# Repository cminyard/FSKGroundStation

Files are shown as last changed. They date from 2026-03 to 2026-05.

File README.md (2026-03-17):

# FSKGroundStation

This is a hardware design for a low-cost PacSat satellite ground
station, but it is also general two-way FSK commmunication for the 2
meter and 70 centimeter bands.  It should be possible to build these
in the US $60 range in quantity.  It can do FSK variants ([G]MSK,
[G]FSK, OOK, ASK).  Notably, it cannot do AFSK, the normal 1200bps
communication used over FM radios.

Basically, this is two radios, one for around 136-175MHz, and one for
around 430-450MHz.  Each of these radios is a simplex two-way radio
using a basic ISM radio chip.  It then has an RF power amplifier (PA)
on the TX side to boost the power to the 4-5 watt range and an RF
switch after than to switch between transmit and receive.

The radios are TI CC1125 chips.  These are standard ISM radio chips.
However, those chips are not able to do HDLC or G3RUH 9600 as used in
standard amateur radio communication.  For that, the CC1125 can
send/receive raw FSK data out a GPIO port.  A Lattice ICE40LP1K FPGA
processes the FSK to be able to do HDLC and whitening per G3RUH.

These chips are controlled by a TI CC27x5 processor over SPI.  Also,
this is designed to have enough capability to run as a stand-alone
application, like for a balloon, fox, control device, or something of
that nature.

## Host Communication

Communication with the host is through a MSPM0G5187 processor that has
USB.  It has a SPI connection to the main processor.

There is also a 2.4GHz radio on the CC27x5 processor, so a bluetooth
connection could be done.

## RF Connections

RF input/output is through SMA connectors on the end of the board.
One connector is for 2 meters only, one is for 70cm only, and one has
a diplexer on it and can be used with a dual-band antenna.  You lose
about 1dB in the diplexer, so it's slightly better to have two
antennas.

There are two open-collector (open drain, really) outputs on a 3.5mm
audio-type jack that the CPU can drive for controlling external
amplifiers or for anything else, really.

Note that you really can't transmit on both bands at the same time.
Power draw would go somewhat above 4A and heat dissipation would be a
problem.  If you have a power source that can supply that it might be
ok, but it's pushing things on the heat side.

## Powering the Board

You can use either of the two USB connectors on the board to supply
power.  To use the host connector (J3), install the jumper on J8.  A
second USB connector J10 is a power-only USB connector that can be
used to power the board if the host connection cannot supply enough
current.  To use that install the J11 jumper.

There is also J25, a standard 6.0mm OD 2.5mm ID barrel connector on
the board, center pin is +5V and the outside is ground, as usual.  You
must remove the other power jumpers (J8 and J11) to use this.

All power connectors must supply at least 3A for transmit.

## Clocks

The MSPM0G5187 has a 32.768kHz clock with enough precision to handle
the USB connection.  In addition, it's internal oscillator has a high
precision resistor, so it should be good.

The 32.768kHz oscillator is output and send to the CC27x5 processor.
The CC27x5 processor has it's own 48MHz oscillator with 20ppm
precision.

The MSPM0G5187 also outputs a basic clock that is used to clock the
FPGA.

The CC1125 chips each have their own 40MHz 20ppm TXCO.

## Heat Dissipation and Measurement

The PAs produce a lot of heat.  At full power they will be dissipating
around 4 watts.  The heat mostly comes out through the bottom of the
board on a 2.5mm square copper pad under each PA.

There are a bunch of vias on the edge of the board and three
unobstructed ground planes between these vias and the PAs.  With edge
plating, this should be able to move heat from the ground planes into
the chassis from the edge.  This is experimental.

In case the edge vias and plating don't work, the 2.5mm square copper
pad under the PAs is left bare.  That way a thermally conductive pad
or a heat sink can be put on that to move heat away.

There are two thermsistors on the board, one mounted by each PA, for
measuring temperature.

## Design Variants

Lots of things can be removed if not required, which will decrease the
price and allow slight performance improvements in some cases:

* The 3.5mm external PA control jack and associated circuits can be
  removed if not necessary.

* PacSat satellites transmit on 70cm and receive on 2m, so the ground
  station for that really only has to transmit on 2m and receive on
  70cm.  The 70cm transmit circuits could be removed and the 2m
  receive circuits could be removed.  That means you can remove the RF
  switches on the, gaining about 1dB.  That, of course, makes the
  board less flexible for other purposes.
  
* The diplexer and connector can be removed if not needed.

* If only the diplexer is used, the TX and RX connectors can be removed.

* The radios can be modified to different bands up to the capabilities
  of the various parts.  The limiting factor is the bands supported by
  the radios (TI CC1312R and CC1125 chips) and the capabilities of the
  PA (Guerrilla RF GRF5604, 100-600MHz).

* The power connectors that aren't used can be removed.

## A Box

This was designed to go into a 100mm x 88mm box like:

    JIUWU Surface Drawing Split Aluminum Enclosure Project Box
	Electronic Enclosure Case for PCB Board DIY, 88x38x100mm (WHL),
	Black

on Amazon.  The actual board dimensions are 83mm x 100mm, it should
slide into the slots in the chassis, which is supposed to be 84mm
wide.

## TODO list

* Figure out how to handle heat from the PAs.

  * Screw mount on the bottom.  This would probably require putting
    the external connectors on the bottom of the board to give space
    in a box.  It would also require ventilation of some type and
    maybe a fan.
	
  * Connect a heat transfer device to the box surface.  This would
    require mounting in a box.  If you use the box referenced above,
    there is a 5.2mm gap between the bottom of the circuit board and the
    inside of the box.  I'm not sure how to conduct the head, though.

  * Wurth has some "Graphite Foam Gaskets" that have high thermal
    conductivity and are not electrically conductive, from what I can
    tell (1KV/mm dialectric strength), and not too expensive.  Laird
    has "Thermal Transfer Gaskets," which look similar.  Also
    Bergquist thermally conductive gap pads.  You could put that
    between the PA pad and the chassis.  I can't find one that's the
    right height, though, it needs to be 5.2mm.  Maybe it can be cut?
    The custom make them, but that would be expensive.

  * It would be possible to use 2oz copper on the inner and/or outer
    layers.  This will conduct a lot more heat, but limits the board
    stacks that can be used and requires some impedance adjustments.

  * The edges of the board could be plated, allowing heat transfer out
    of the edges of the board into the chassis.

* The 2m connection to the CC1312R is actually for 169MHz.  A proper
  design for 145MHz needs to be found, or it will need to be tweaked.

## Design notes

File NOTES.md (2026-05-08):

Notes on the FSK Ground Station
===============================

This keeps track of history, general information, things that need to
be done, and things that have been done.

The general information will probably make it into another document at
some point.

# TODO

I discovered that the CC1125 lets you have direct control over the TX
output and direct read access to the RX frequency offset.  See "5.2.4
Custom Frequency Modulation(CFM)/Analog FM" in the manual.  It appears
you can set up the chip to continuously read/write these values
through the SPI interface.  With this, we have the possibility of
directly modulating and just using the CC1125 as an RF front-end.  You
could probably do AFSK with this.  You could get certainty information
on bits for doing soft decoding of FEC.  This will require some
redesign.  To use this requires a dedicated SPI interface for each
radio.  This would require a new CPU or using the FPGA to do the SPI
interfaces to the radios.  It would also require doing signal
processing somewhere for AFSK.

When a smaller version of the MSPM0G5187 comes out, switch to it.  The
64-pin LQFP takes up a lot of space and has tons more pins than this
needs.

It is unfortunate that two CPU chips are required for this.  But the
existing USB chips have proprietary elements and very poor
documentation if you are doing anything but a serial port.  Plus they
are more expensive than the MSPM0G5187.  But I couldn't find a chip
that had enough FLASH and RAM, bluetooth, and USB.

# Done

Possibly replace the USB chip with a MSPM0G5187.  It's a
microprocessor with a USB interface, and it's actually cheaper than
the CY7C65215-32LTXI and it frees us from using lousy libraries from
the vendor and proprietary programming tools.

# Not going to do

# Chip Selection and Possibilities

PA final: PD55015 15W 15dB gain, 12.5V, could be pushed a bit

PA stage 1: GRF5030, GRF5040, GRF5112, GRF5115, etc.  Some Qorvo chips
would work.

GRF5604 is capable of 6 watts (38dBm, 37dB gain) and it is a two-stage
design, so only one chip is needed to get to 6 watts.  This was chosen
for now.

For the radios, a large number of ISM chips are available, but few
will do 144-149 MHz.  The TI CC1312R and C1352R are Cortex M4F CPUs
with an attached radio.  They cannot do HDLC, though.

The TI CC12xx series of radios are similar to the CC1312R but stand
alone radios.  They will not directly do HDLC or the G3RUH whitening,
but they have something called "Synchronous serial mode" that appears
to put/get the FSK directly on GPIO pins, so you could do HDLC on an
external chip.  It also has something called "Transparent mode" that
appears to give direct access to ADC info and the TX synthesizer.

The Silicon Labs 446x series of radio chips is very similar to the TI
CC12xx series.  It has "direct mode" which inputs/outputs FSK and "raw
data mode" which is the ADC and TX synthesizer access.

For bit handling (HDLC and whitening), the Lattice iCE40 LP/HX series
of FPGAs looks good.  Probably the LP640 or the LP1K.

For a USB interface, FTDI has a bunch of chips that look workable.
They are on the expensive side, though.

Infineon has some chips, too, and CY7C65215-32LTXI looks good.  It has
a dual interface that can do UART, SPI, and I2C.  The plan is to do
UART and SPI for the host interface.  One problem is that the various
chips (from FTDI, Microchip, Infineon) have very poor documentation on
how to program them; they expect you to use their libraries

TI and some others make a chip with USB that could be used, too.  It's
cheaper, and it doesn't tie us to proprietary tools.

If we use the CC1352R, it can also do Bluetooth, which might be nice
for a host interface.  It doesn't cost a lot more than the CC1312R.

If we have two independent radio chips, then other non-radio
processors can be used.  The Cortex-M0+ processors could be used,
though they are limited in RAM, but they cost less than $1.
Cortex-M4F processors would be better.  It turns out it's cheaper to
buy the CC1312R or CC1352R than just a plain Cortex-M4 from TI.
And the radio chips have more flash and RAM.

But even better, the TI CC2755 chips are cheaper and have even more
FLASH and RAM.  And they can do bluetooth.

# History

## 2026-03-06

Initial basic design was done a few days ago.  Original design was a
CC1312R processor+radio for 144MHz and a CC1125 radio for 440MHz, and
two GRF5604 PAs.  The host interfaced is a CY7C65215-32LTXI.

However, I have discovered that the ISM chips that are cheap and easy
to use will not do HDLC or the G3RUH whitening.  I've also learned
some information about G3RUH:

I had always been a little confused about g3ruh modulation based on my
understanding of how modulation works and what g3ruh does.  I had
heard that g3ruh was GMSK.  That's not true, it's GFSK.  I had
wondered how it knew where the zero crossings were.  There's actually
a note in the PacSat software saying that GMSK didn't work on receive
and they had to use GFSK to receive.  And now I know why.  You can
transmit GMSK and a GFSK receiver will receive it, but you cannot
transmit GFSK and have a GMSK receiver receive it.  Unfortunately,
there's no really good explanation about g3ruh, I had to reverse
engineer it from the hardware design.

I then spent some time looking at the ISM radios.  It turns out they
don't support HDLC and lack a compatible whitening algorithm.  If you
remember I said that MSK doesn't require periodic bit shifts, you can
use zero crossings to keep the receiver in alignment.  And that's what
they have done.  They generally transmit a 32-bit sequence to start a
packet, and if the receiver sees that it assumes the start of a packet
has happened.  Not as robust as HDLC, really.  So they won't talk to a
g3ruh radio.  In fact, I don't think they will talk to an ax5043 at
all in any mode.

However, all is not lost.  I did find some radios that will
input/output a raw FSK stream to a pin.  One is already in my current
board design.  You would need to add an FPGA to take that data stream
and do the whitening and HDLC.  It will raise the cost of the board a
bit, $3 or so, but that's not a big deal.  You will also need another
separate radio chip.

I have some open questions out to TI on this, but it looks doable.

So looking at a redesign, it's the CC2755R10 chip for the main
processor, two CC1125 chips for radios, and an iCE40 LP1K for an FPGA.
Still two GRF5604 PAs and a CY7C65215-32LTXI host interface.

## 2026-03-10

Finished the rework for two radio chips and the FPGA.

TI confirmed that the synchronous output of the CC115 can be used to
provide our own whitening and HDLC.  The chip does not do differential
coding, so that will have to be accounted for in the FPGA, too.

## 2026-03-11

Change the voltage regulator to a diode for 2.5V to the FPGA.

Switch to a CPU with a USB interface for the USB connection The part
that was picked had proprietary tools and configuration and it didn't
support interrupts.  The CPU is cheaper and more capable.
Unfortunately it's a lot bigger.  A newer smaller part may come out at
some time, switch then.

## 2026-03-12

Add a clock line from the USB chip to the FPGA so the FPGA can have a
clock.

Split the reset lines so that the USB chips controls the main CPUs
reset line.  This way they don't share the same reset, which should
simplify things.

## 2026-03-15

Add DNP resistors on the unused pins of the CPU and the USB chip.

## 2026-03-16

Move the diplexer parts close to the sources so there's not a big stub
when not using the diplexer.

## 2026-04-06

Replace the FPGA with a QFP one.  It has more pins, which might be
useful, and it's easier to work with than the BGA.  It also has a
built-in SPI.  It's currently an ICE40UP5K, but the ICE5LP[124]K chips
are pin compatible and cheaper.

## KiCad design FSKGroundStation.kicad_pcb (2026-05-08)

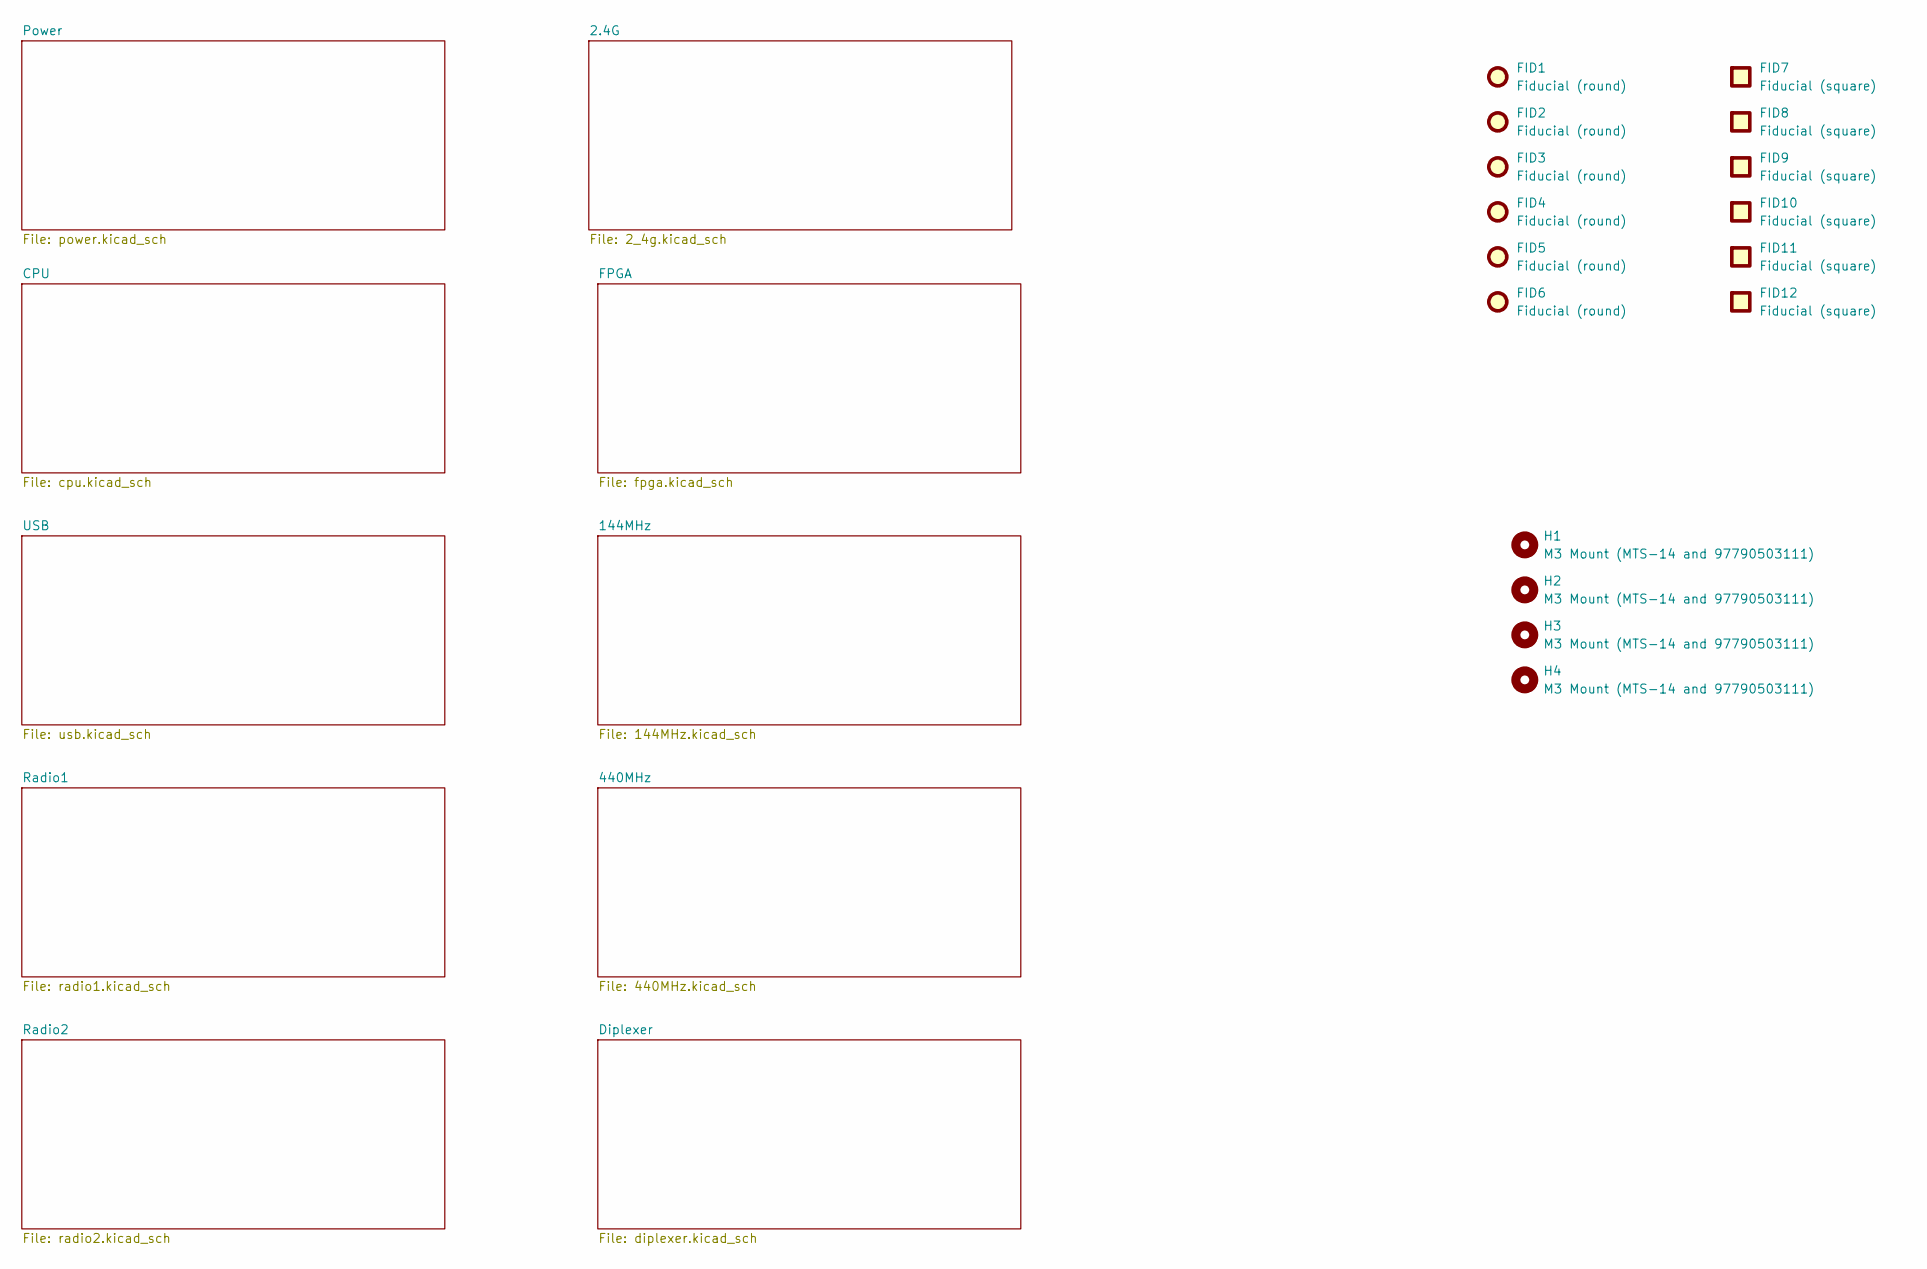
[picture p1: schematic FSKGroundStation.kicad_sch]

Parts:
FID1, FID2, FID3, FID4, FID5, FID6: Fiducial (round); Fiducial_1mm_Mask2mm
FID7, FID8, FID9, FID10, FID11, FID12: Fiducial (square); Fiducial_Square_1mm_Mask2mm
H1, H2, H3, H4: M3 Mount (MTS-14 and 97790503111); MountingHole_3.2mm_M3

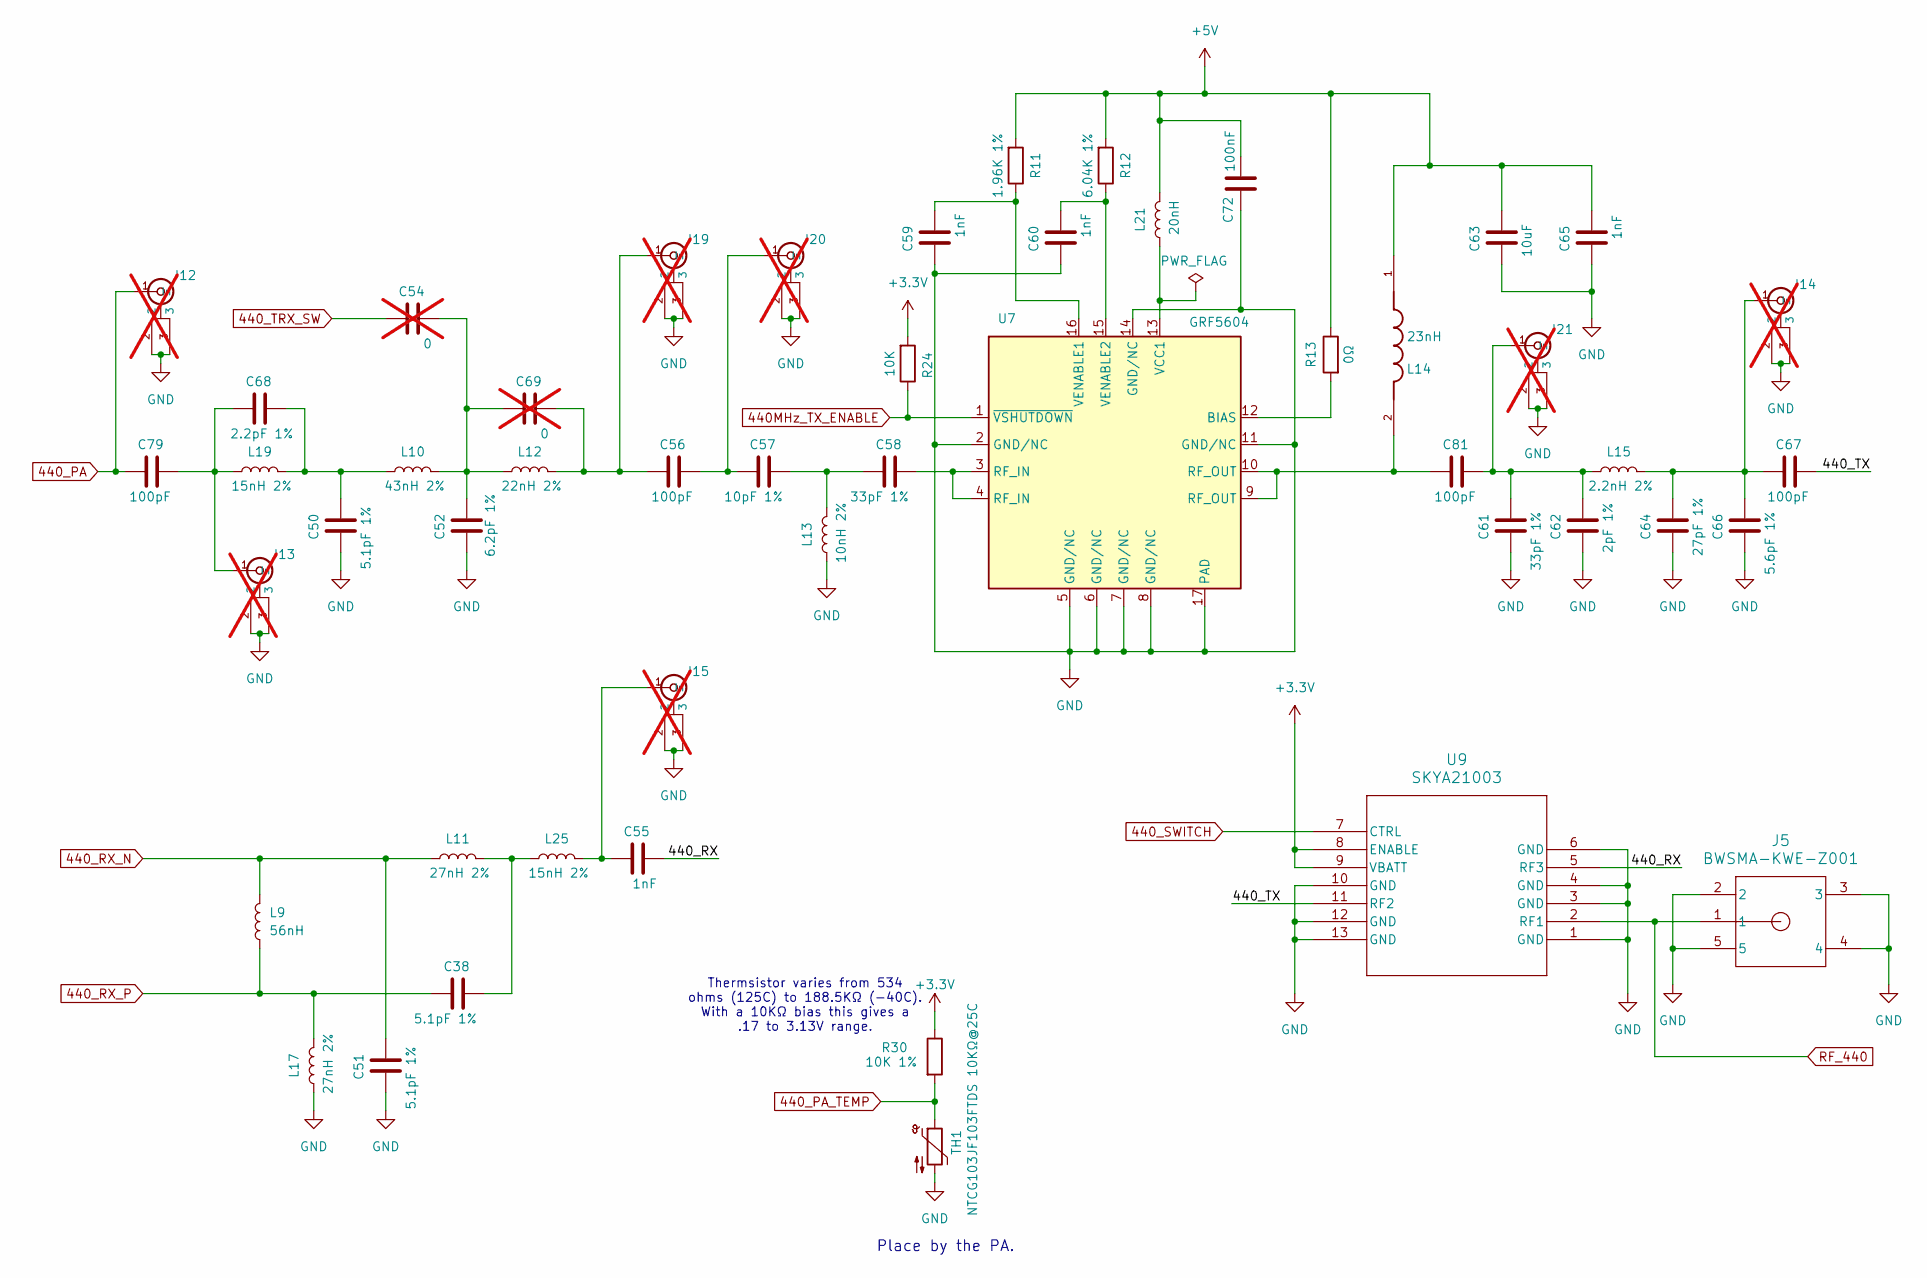
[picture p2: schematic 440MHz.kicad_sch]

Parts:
C38, C50, C51: 5.1pF 1%; C_0402_1005Metric_Pad0.74x0.62mm_HandSolder
C52: 6.2pF 1%; C_0402_1005Metric_Pad0.74x0.62mm_HandSolder
C54, C69: 0; C_0402_1005Metric_Pad0.74x0.62mm_HandSolder; not fitted
C55, C59, C60, C65: 1nF; C_0402_1005Metric_Pad0.74x0.62mm_HandSolder
C56, C67, C79, C81: 100pF; C_0402_1005Metric_Pad0.74x0.62mm_HandSolder
C57: 10pF 1%; C_0402_1005Metric_Pad0.74x0.62mm_HandSolder
C58, C61: 33pF 1%; C_0402_1005Metric_Pad0.74x0.62mm_HandSolder
C62: 2pF 1%; C_0402_1005Metric_Pad0.74x0.62mm_HandSolder
C63: 10uF; C_1206_3216Metric_Pad1.33x1.80mm_HandSolder
C64: 27pF 1%; C_0402_1005Metric_Pad0.74x0.62mm_HandSolder
C66: 5.6pF 1%; C_0402_1005Metric_Pad0.74x0.62mm_HandSolder
C68: 2.2pF 1%; C_0402_1005Metric_Pad0.74x0.62mm_HandSolder
C72: 100nF; C_0402_1005Metric_Pad0.74x0.62mm_HandSolder
J5: BWSMA-KWE-Z001; CONN_BWSMA-KWE-Z001_BAT
J12, J13, J14, J15, J19, J20, J21: CONN1_CONUFL_TEC; not fitted
L9: 56nH; L_0603_1608Metric_Pad1.05x0.95mm_HandSolder
L10: 43nH 2%; L_0402_1005Metric_Pad0.77x0.64mm_HandSolder
L11, L17: 27nH 2%; L_0402_1005Metric_Pad0.77x0.64mm_HandSolder
L12: 22nH 2%; L_0402_1005Metric_Pad0.77x0.64mm_HandSolder
L13: 10nH 2%; L_0402_1005Metric_Pad0.77x0.64mm_HandSolder
L14: 23nH; IND_0908SQ-23NJLC; PARTREV 12/21/22
L15: 2.2nH 2%; L_0402_1005Metric_Pad0.77x0.64mm_HandSolder
L19, L25: 15nH 2%; L_0402_1005Metric_Pad0.77x0.64mm_HandSolder
L21: 20nH; L_0402_1005Metric_Pad0.77x0.64mm_HandSolder
R11: 1.96K 1%; R_0402_1005Metric
R12: 6.04K 1%; R_0402_1005Metric
R13: 0Ω; R_0402_1005Metric
R24: 10K; R_0402_1005Metric
R30: 10K 1%; R_0402_1005Metric_Pad0.72x0.64mm_HandSolder
TH1: NTCG103JF103FTDS 10KΩ@25C; R_0402_1005Metric
U7: GRF5604; QFN-16-1EP_3x3mm_P0.5mm_EP1.7x1.7mm
U9: SKYA21003; QFN12_SKYA21003_SKY

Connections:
440MHz_TX_ENABLE: R24.1, U7.1 (~VSHUTDOWN); also elsewhere on the board
440_PA: C79.1, J12.1 (In); also elsewhere on the board
440_PA_TEMP: R30.2, TH1.1; also elsewhere on the board
440_RX_N: C51.2, L9.2, L11.1; also elsewhere on the board
440_RX_P: C38.1, L9.1, L17.2; also elsewhere on the board
440_SWITCH: U9.7 (CTRL); also elsewhere on the board
440_TRX_SW: C54.1; also elsewhere on the board
+3.3V: R24.2, R30.1, U9.8 (ENABLE), U9.9 (VBATT); also elsewhere on the board
+5V: C63.2, C65.2, C72.2, L14.1, L21.2, R11.2, R12.2, R13.1; also elsewhere on the board
/440MHz/440_RX: C55.2, U9.5 (RF3)
/440MHz/440_TX: C67.2, U9.11 (RF2)
GND: C50.1, C51.1, C52.1, C59.1, C60.1, C61.1, C62.1, C63.1, C64.1, C65.1, C66.1, C72.1, J5.2, J5.3, J5.4, J5.5, J12.2, J12.3, J13.2, J13.3, J14.2, J14.3, J15.2, J15.3, J19.2, J19.3, J20.2, J20.3, J21.2, J21.3, L13.1, L17.1, TH1.2, U7.2 (GND/NC), U7.5 (GND/NC), U7.6 (GND/NC), U7.7 (GND/NC), U7.8 (GND/NC), U7.11 (GND/NC), U7.14 (GND/NC), U7.17 (PAD), U9.1 (GND), U9.3 (GND), U9.4 (GND), U9.6 (GND), U9.10 (GND), U9.12 (GND), U9.13 (GND); also elsewhere on the board
unnamed: C38.2, L11.2, L25.1
unnamed: C50.2, C68.2, L10.1, L19.2
unnamed: C52.2, C54.2, C69.1, L10.2, L12.1
unnamed: C57.2, C58.1, L13.2
unnamed: C58.2, U7.3 (RF_IN), U7.4 (RF_IN)
unnamed: C81.1, L14.2, U7.9 (RF_OUT), U7.10 (RF_OUT)
unnamed: C68.1, C79.2, J13.1 (In), L19.1
unnamed: C64.2, C66.2, C67.1, J14.1 (In), L15.2
unnamed: C55.1, J15.1 (In), L25.2
unnamed: C56.1, C69.2, J19.1 (In), L12.2
unnamed: C56.2, C57.1, J20.1 (In)
unnamed: C61.2, C62.2, C81.2, J21.1 (In), L15.1
unnamed: R13.2, U7.12 (BIAS)
unnamed: L21.1, U7.13 (VCC1)
unnamed: C59.2, R11.1, U7.16 (VENABLE1)
unnamed: C60.2, R12.1, U7.15 (VENABLE2)
RF_440: J5.1, U9.2 (RF1); also elsewhere on the board

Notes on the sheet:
Thermsistor varies from 534 ohms (125C) to 188.5KΩ (-40C). With a 10KΩ bias this gives a .17 to 3.13V range.
Place by the PA.

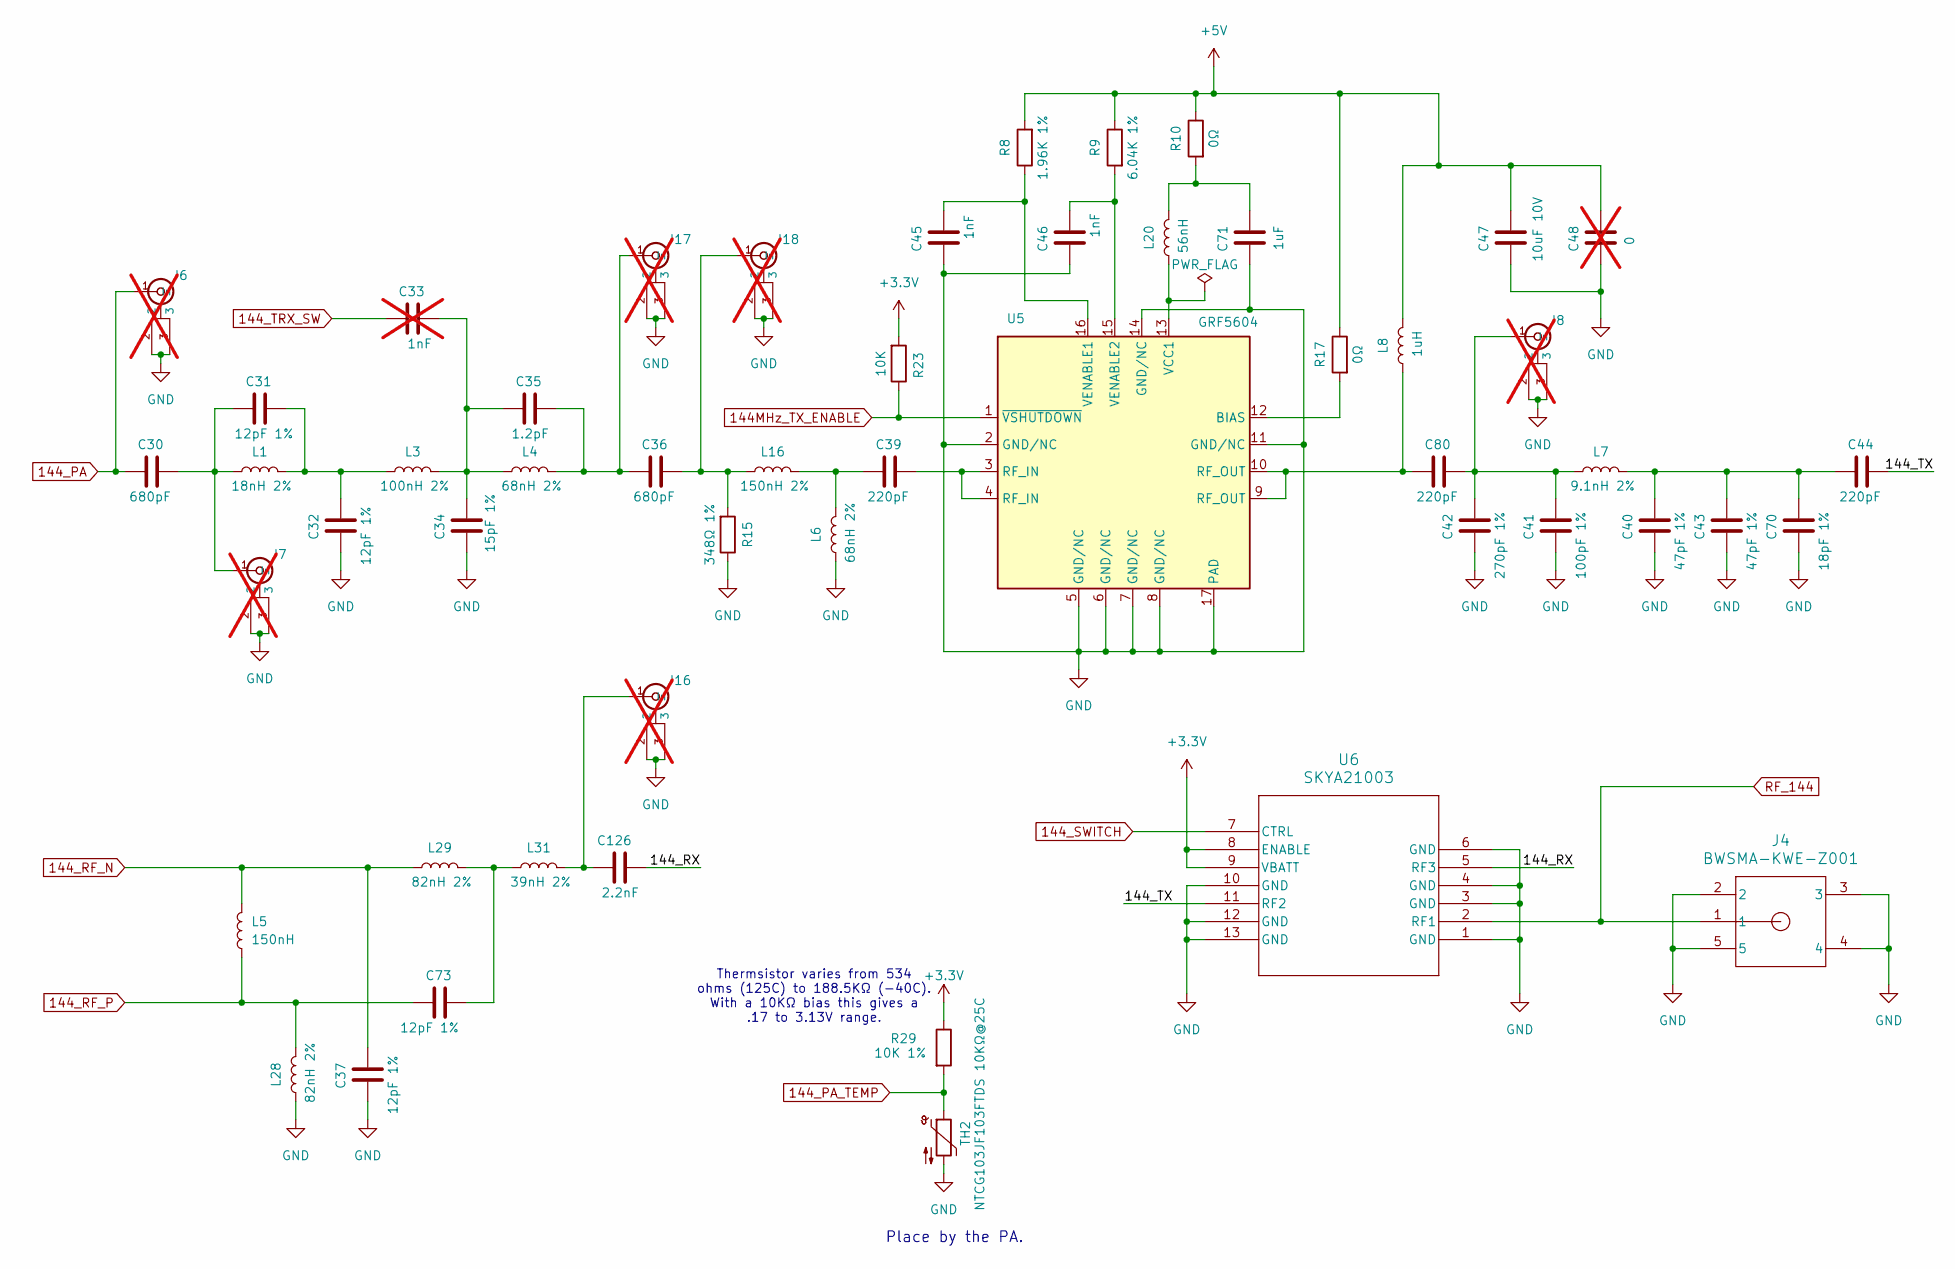
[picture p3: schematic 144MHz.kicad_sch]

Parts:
C30, C36: 680pF; C_0402_1005Metric_Pad0.74x0.62mm_HandSolder
C31, C32, C37, C73: 12pF 1%; C_0402_1005Metric_Pad0.74x0.62mm_HandSolder
C33: 1nF; C_0402_1005Metric_Pad0.74x0.62mm_HandSolder; not fitted
C34: 15pF 1%; C_0402_1005Metric_Pad0.74x0.62mm_HandSolder
C35: 1.2pF; C_0402_1005Metric_Pad0.74x0.62mm_HandSolder
C39, C44, C80: 220pF; C_0402_1005Metric_Pad0.74x0.62mm_HandSolder
C40, C43: 47pF 1%; C_0402_1005Metric_Pad0.74x0.62mm_HandSolder
C41: 100pF 1%; C_0402_1005Metric_Pad0.74x0.62mm_HandSolder
C42: 270pF 1%; C_0402_1005Metric_Pad0.74x0.62mm_HandSolder
C45, C46: 1nF; C_0402_1005Metric_Pad0.74x0.62mm_HandSolder
C47: 10uF 10V; C_1206_3216Metric_Pad1.33x1.80mm_HandSolder
C48: 0; C_0402_1005Metric_Pad0.74x0.62mm_HandSolder; not fitted
C70: 18pF 1%; C_0402_1005Metric_Pad0.74x0.62mm_HandSolder
C71: 1uF; C_0603_1608Metric_Pad1.08x0.95mm_HandSolder
C126: 2.2nF; C_0402_1005Metric_Pad0.74x0.62mm_HandSolder
J4: BWSMA-KWE-Z001; CONN_BWSMA-KWE-Z001_BAT
J6, J7, J8, J16, J17, J18: CONN1_CONUFL_TEC; not fitted
L1: 18nH 2%; L_0402_1005Metric_Pad0.77x0.64mm_HandSolder
L3: 100nH 2%; L_0603_1608Metric_Pad1.05x0.95mm_HandSolder
L4, L6: 68nH 2%; L_0603_1608Metric_Pad1.05x0.95mm_HandSolder
L5: 150nH; L_0805_2012Metric_Pad1.05x1.20mm_HandSolder
L7: 9.1nH 2%; L_0402_1005Metric_Pad0.77x0.64mm_HandSolder
L8: 1uH; L_1008_2520Metric_Pad1.43x2.20mm_HandSolder
L16: 150nH 2%; L_0805_2012Metric_Pad1.05x1.20mm_HandSolder
L20: 56nH; L_0603_1608Metric_Pad1.05x0.95mm_HandSolder
L28, L29: 82nH 2%; L_0603_1608Metric_Pad1.05x0.95mm_HandSolder
L31: 39nH 2%; L_0402_1005Metric_Pad0.77x0.64mm_HandSolder
R8: 1.96K 1%; R_0402_1005Metric
R9: 6.04K 1%; R_0402_1005Metric
R10, R17: 0Ω; R_0402_1005Metric
R15: 348Ω 1%; R_0402_1005Metric
R23: 10K; R_0402_1005Metric
R29: 10K 1%; R_0402_1005Metric_Pad0.72x0.64mm_HandSolder
TH2: NTCG103JF103FTDS 10KΩ@25C; R_0402_1005Metric
U5: GRF5604; QFN-16-1EP_3x3mm_P0.5mm_EP1.7x1.7mm
U6: SKYA21003; QFN12_SKYA21003_SKY

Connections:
144MHz_TX_ENABLE: R23.1, U5.1 (~VSHUTDOWN); also elsewhere on the board
144_PA: C30.1, J6.1 (In); also elsewhere on the board
144_PA_TEMP: R29.2, TH2.1; also elsewhere on the board
144_RF_N: C37.2, L5.2, L29.1; also elsewhere on the board
144_RF_P: C73.1, L5.1, L28.2; also elsewhere on the board
144_SWITCH: U6.7 (CTRL); also elsewhere on the board
144_TRX_SW: C33.1; also elsewhere on the board
+3.3V: R23.2, R29.1, U6.8 (ENABLE), U6.9 (VBATT); also elsewhere on the board
+5V: C47.2, C48.2, L8.2, R8.2, R9.1, R10.1, R17.1; also elsewhere on the board
/144MHz/144_RX: C126.2, U6.5 (RF3)
/144MHz/144_TX: C44.2, U6.11 (RF2)
GND: C32.1, C34.1, C37.1, C40.1, C41.1, C42.1, C43.1, C45.1, C46.1, C47.1, C48.1, C70.1, C71.1, J4.2, J4.3, J4.4, J4.5, J6.2, J6.3, J7.2, J7.3, J8.2, J8.3, J16.2, J16.3, J17.2, J17.3, J18.2, J18.3, L6.1, L28.1, R15.1, TH2.2, U5.2 (GND/NC), U5.5 (GND/NC), U5.6 (GND/NC), U5.7 (GND/NC), U5.8 (GND/NC), U5.11 (GND/NC), U5.14 (GND/NC), U5.17 (PAD), U6.1 (GND), U6.3 (GND), U6.4 (GND), U6.6 (GND), U6.10 (GND), U6.12 (GND), U6.13 (GND); also elsewhere on the board
unnamed: C31.2, C32.2, L1.2, L3.1
unnamed: C33.2, C34.2, C35.1, L3.2, L4.1
unnamed: C39.1, L6.2, L16.2
unnamed: C39.2, U5.3 (RF_IN), U5.4 (RF_IN)
unnamed: C40.2, C43.2, C44.1, C70.2, L7.2
unnamed: C71.2, L20.2, R10.2
unnamed: C73.2, L29.2, L31.1
unnamed: C80.1, L8.1, U5.9 (RF_OUT), U5.10 (RF_OUT)
unnamed: C30.2, C31.1, J7.1 (In), L1.1
unnamed: C41.2, C42.2, C80.2, J8.1 (In), L7.1
unnamed: C126.1, J16.1 (In), L31.2
unnamed: C35.2, C36.1, J17.1 (In), L4.2
unnamed: C36.2, J18.1 (In), L16.1, R15.2
unnamed: R17.2, U5.12 (BIAS)
unnamed: L20.1, U5.13 (VCC1)
unnamed: C45.2, R8.1, U5.16 (VENABLE1)
unnamed: C46.2, R9.2, U5.15 (VENABLE2)
RF_144: J4.1, U6.2 (RF1); also elsewhere on the board

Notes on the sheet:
Thermsistor varies from 534 ohms (125C) to 188.5KΩ (-40C). With a 10KΩ bias this gives a .17 to 3.13V range.
Place by the PA.

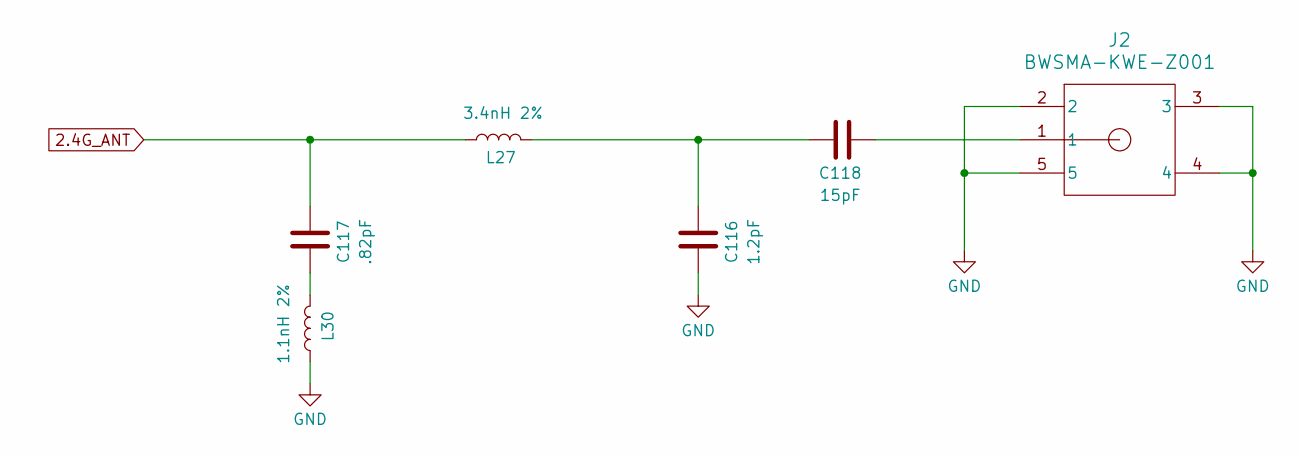
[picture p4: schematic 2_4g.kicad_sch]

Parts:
C116: 1.2pF; C_0402_1005Metric_Pad0.74x0.62mm_HandSolder
C117: .82pF; C_0402_1005Metric_Pad0.74x0.62mm_HandSolder
C118: 15pF; C_0402_1005Metric_Pad0.74x0.62mm_HandSolder
J2: BWSMA-KWE-Z001; CONN_BWSMA-KWE-Z001_BAT
L27: 3.4nH 2%; L_0402_1005Metric_Pad0.77x0.64mm_HandSolder
L30: 1.1nH 2%; L_0402_1005Metric_Pad0.77x0.64mm_HandSolder

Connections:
2.4G_ANT: C117.2, L27.1; also elsewhere on the board
GND: C116.1, J2.2, J2.3, J2.4, J2.5, L30.1; also elsewhere on the board
unnamed: C116.2, C118.1, L27.2
unnamed: C117.1, L30.2
unnamed: C118.2, J2.1

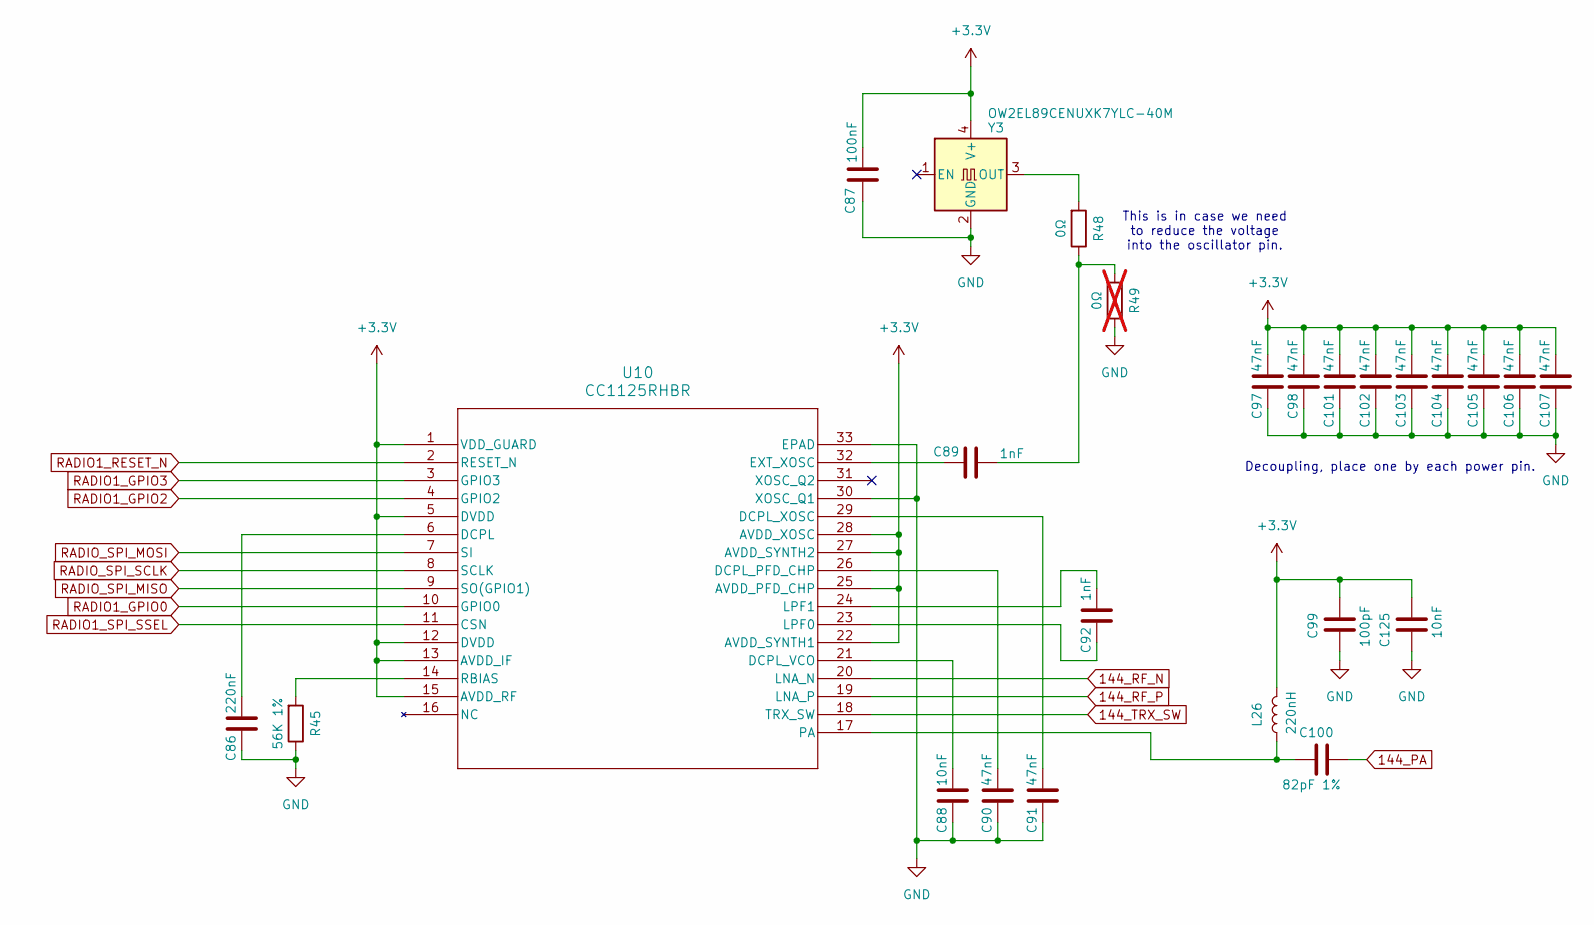
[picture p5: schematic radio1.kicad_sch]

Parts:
C86: 220nF; C_0402_1005Metric_Pad0.74x0.62mm_HandSolder
C87: 100nF; C_0402_1005Metric_Pad0.74x0.62mm_HandSolder
C88, C125: 10nF; C_0402_1005Metric_Pad0.74x0.62mm_HandSolder
C89, C92: 1nF; C_0402_1005Metric_Pad0.74x0.62mm_HandSolder
C90, C91, C97, C98, C101, C102, C103, C104, C105, C106, C107: 47nF; C_0402_1005Metric_Pad0.74x0.62mm_HandSolder
C99: 100pF; C_0402_1005Metric_Pad0.74x0.62mm_HandSolder
C100: 82pF 1%; C_0402_1005Metric_Pad0.74x0.62mm_HandSolder
L26: 220nH; L_0805_2012Metric_Pad1.05x1.20mm_HandSolder
R45: 56K 1%; R_0402_1005Metric
R48: 0Ω; R_0402_1005Metric
R49: 0Ω; R_0402_1005Metric; not fitted
U10: CC1125RHBR; RHB32_3P45X3P45_TEX
Y3: OW2EL89CENUXK7YLC-40M; Oscillator_SMD_SiT_PQFN-4Pin_2.0x1.6mm

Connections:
144_PA: C100.2; also elsewhere on the board
144_RF_N: U10.20 (LNA_N); also elsewhere on the board
144_RF_P: U10.19 (LNA_P); also elsewhere on the board
144_TRX_SW: U10.18 (TRX_SW); also elsewhere on the board
+3.3V: C87.2, C97.2, C98.2, C99.2, C101.2, C102.2, C103.2, C104.2, C105.2, C106.2, C107.2, C125.2, L26.2, U10.1 (VDD_GUARD), U10.5 (DVDD), U10.12 (DVDD), U10.13 (AVDD_IF), U10.15 (AVDD_RF), U10.22 (AVDD_SYNTH1), U10.25 (AVDD_PFD_CHP), U10.27 (AVDD_SYNTH2), U10.28 (AVDD_XOSC), Y3.4 (V+); also elsewhere on the board
GND: C86.1, C87.1, C88.1, C90.1, C91.1, C97.1, C98.1, C99.1, C101.1, C102.1, C103.1, C104.1, C105.1, C106.1, C107.1, C125.1, R45.1, R49.1, U10.30 (XOSC_Q1), U10.33 (EPAD), Y3.2 (GND); also elsewhere on the board
unnamed: C89.2, R48.1, R49.2
unnamed: C86.2, U10.6 (DCPL)
unnamed: C90.2, U10.26 (DCPL_PFD_CHP)
unnamed: C88.2, U10.21 (DCPL_VCO)
unnamed: C91.2, U10.29 (DCPL_XOSC)
unnamed: C89.1, U10.32 (EXT_XOSC)
unnamed: C92.1, U10.23 (LPF0)
unnamed: C92.2, U10.24 (LPF1)
unnamed: C100.1, L26.1, U10.17 (PA)
unnamed: R45.2, U10.14 (RBIAS)
unnamed: R48.2, Y3.3 (OUT)
RADIO1_GPIO0: U10.10 (GPIO0); also elsewhere on the board
RADIO1_GPIO2: U10.4 (GPIO2); also elsewhere on the board
RADIO1_GPIO3: U10.3 (GPIO3); also elsewhere on the board
RADIO1_RESET_N: U10.2 (RESET_N); also elsewhere on the board
RADIO1_SPI_SSEL: U10.11 (CSN); also elsewhere on the board
RADIO_SPI_MISO: U10.9 (SO(GPIO1)); also elsewhere on the board
RADIO_SPI_MOSI: U10.7 (SI); also elsewhere on the board
RADIO_SPI_SCLK: U10.8 (SCLK); also elsewhere on the board

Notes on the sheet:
This is in case we need to reduce the voltage into the oscillator pin.
Decoupling, place one by each power pin.

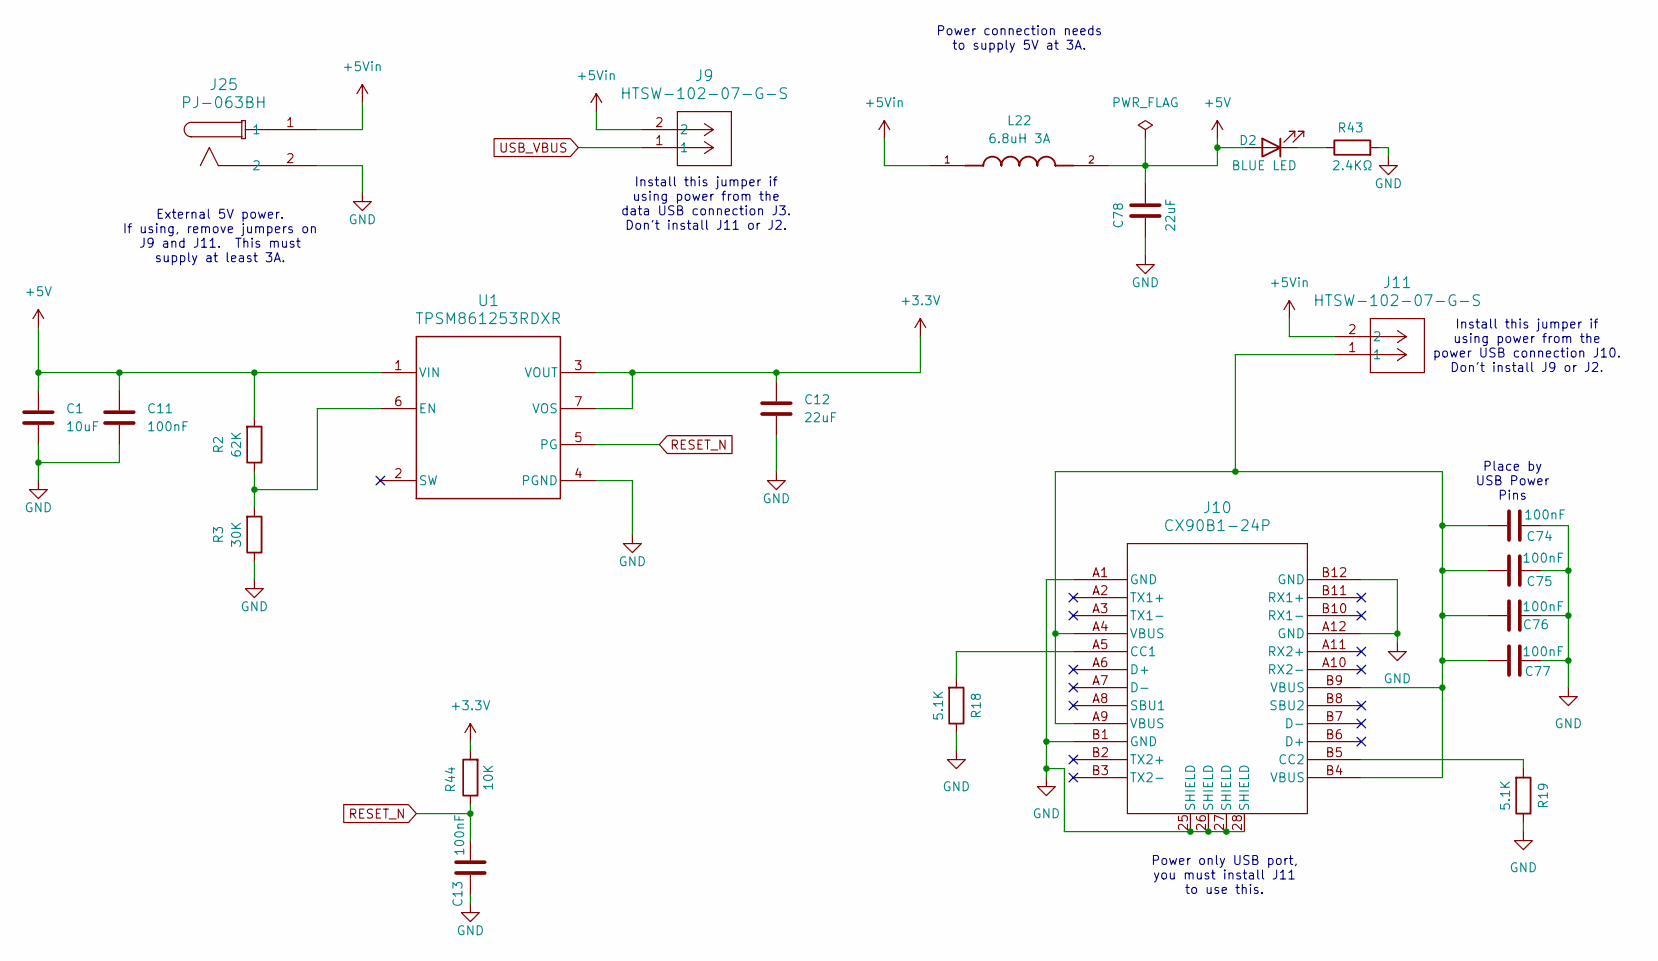
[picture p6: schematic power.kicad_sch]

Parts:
C1: 10uF; C_1206_3216Metric_Pad1.33x1.80mm_HandSolder
C11, C13: 100nF; C_0402_1005Metric_Pad0.74x0.62mm_HandSolder
C12, C78: 22uF; C_1206_3216Metric_Pad1.33x1.80mm_HandSolder
C74, C75, C76, C77: 100nF; C_0402_1005Metric
D2: BLUE LED; LED_0603_1608Metric_Pad1.05x0.95mm_HandSolder
J9, J11: HTSW-102-07-G-S; CON2_1X2_TU_TSW
J10: CX90B1-24P; CX90B1-24P_HIR
J25: PJ-063BH; PJ-063BH_CUD
L22: 6.8uH 3A; IND_1255AY-6R8M=P3; PARTREV N/A; DigiKey_Part_Number 490-14063-1-ND
R2: 62K; R_0402_1005Metric
R3: 30K; R_0402_1005Metric
R18, R19: 5.1K; R_0402_1005Metric
R43: 2.4KΩ; R_0603_1608Metric_Pad0.98x0.95mm_HandSolder
R44: 10K; R_0402_1005Metric
U1: TPSM861253RDXR; RDX0007A-MFG

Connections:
+3.3V: C12.1, R44.2, U1.3 (VOUT), U1.7 (VOS); also elsewhere on the board
+5V: C1.1, C11.1, C78.2, D2.2 (A), L22.2, R2.2, U1.1 (VIN); also elsewhere on the board
+5Vin: J9.2, J11.2, J25.1, L22.1
GND: C1.2, C11.2, C12.2, C13.1, C74.2, C75.2, C76.2, C77.2, C78.1, J10.25 (SHIELD), J10.26 (SHIELD), J10.27 (SHIELD), J10.28 (SHIELD), J10.A1 (GND), J10.A12 (GND), J10.B1 (GND), J10.B12 (GND), J25.2, R3.1, R18.1, R19.1, R43.2, U1.4 (PGND); also elsewhere on the board
unnamed: C74.1, C75.1, C76.1, C77.1, J10.A4 (VBUS), J10.A9 (VBUS), J10.B4 (VBUS), J10.B9 (VBUS), J11.1
unnamed: D2.1 (K), R43.1
unnamed: J10.A5 (CC1), R18.2
unnamed: J10.B5 (CC2), R19.2
unnamed: R2.1, R3.2, U1.6 (EN)
RESET_N: C13.2, R44.1, U1.5 (PG); also elsewhere on the board
USB_VBUS: J9.1; also elsewhere on the board

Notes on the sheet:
Power connection needs to supply 5V at 3A.
Power only USB port, you must install J11 to use this.
Install this jumper if using power from the data USB connection J3. Don't install J11 or J2.
Place by USB Power Pins
External 5V power. If using, remove jumpers on J9 and J11. This must supply at least 3A.
Install this jumper if using power from the power USB connection J10. Don't install J9 or J2.

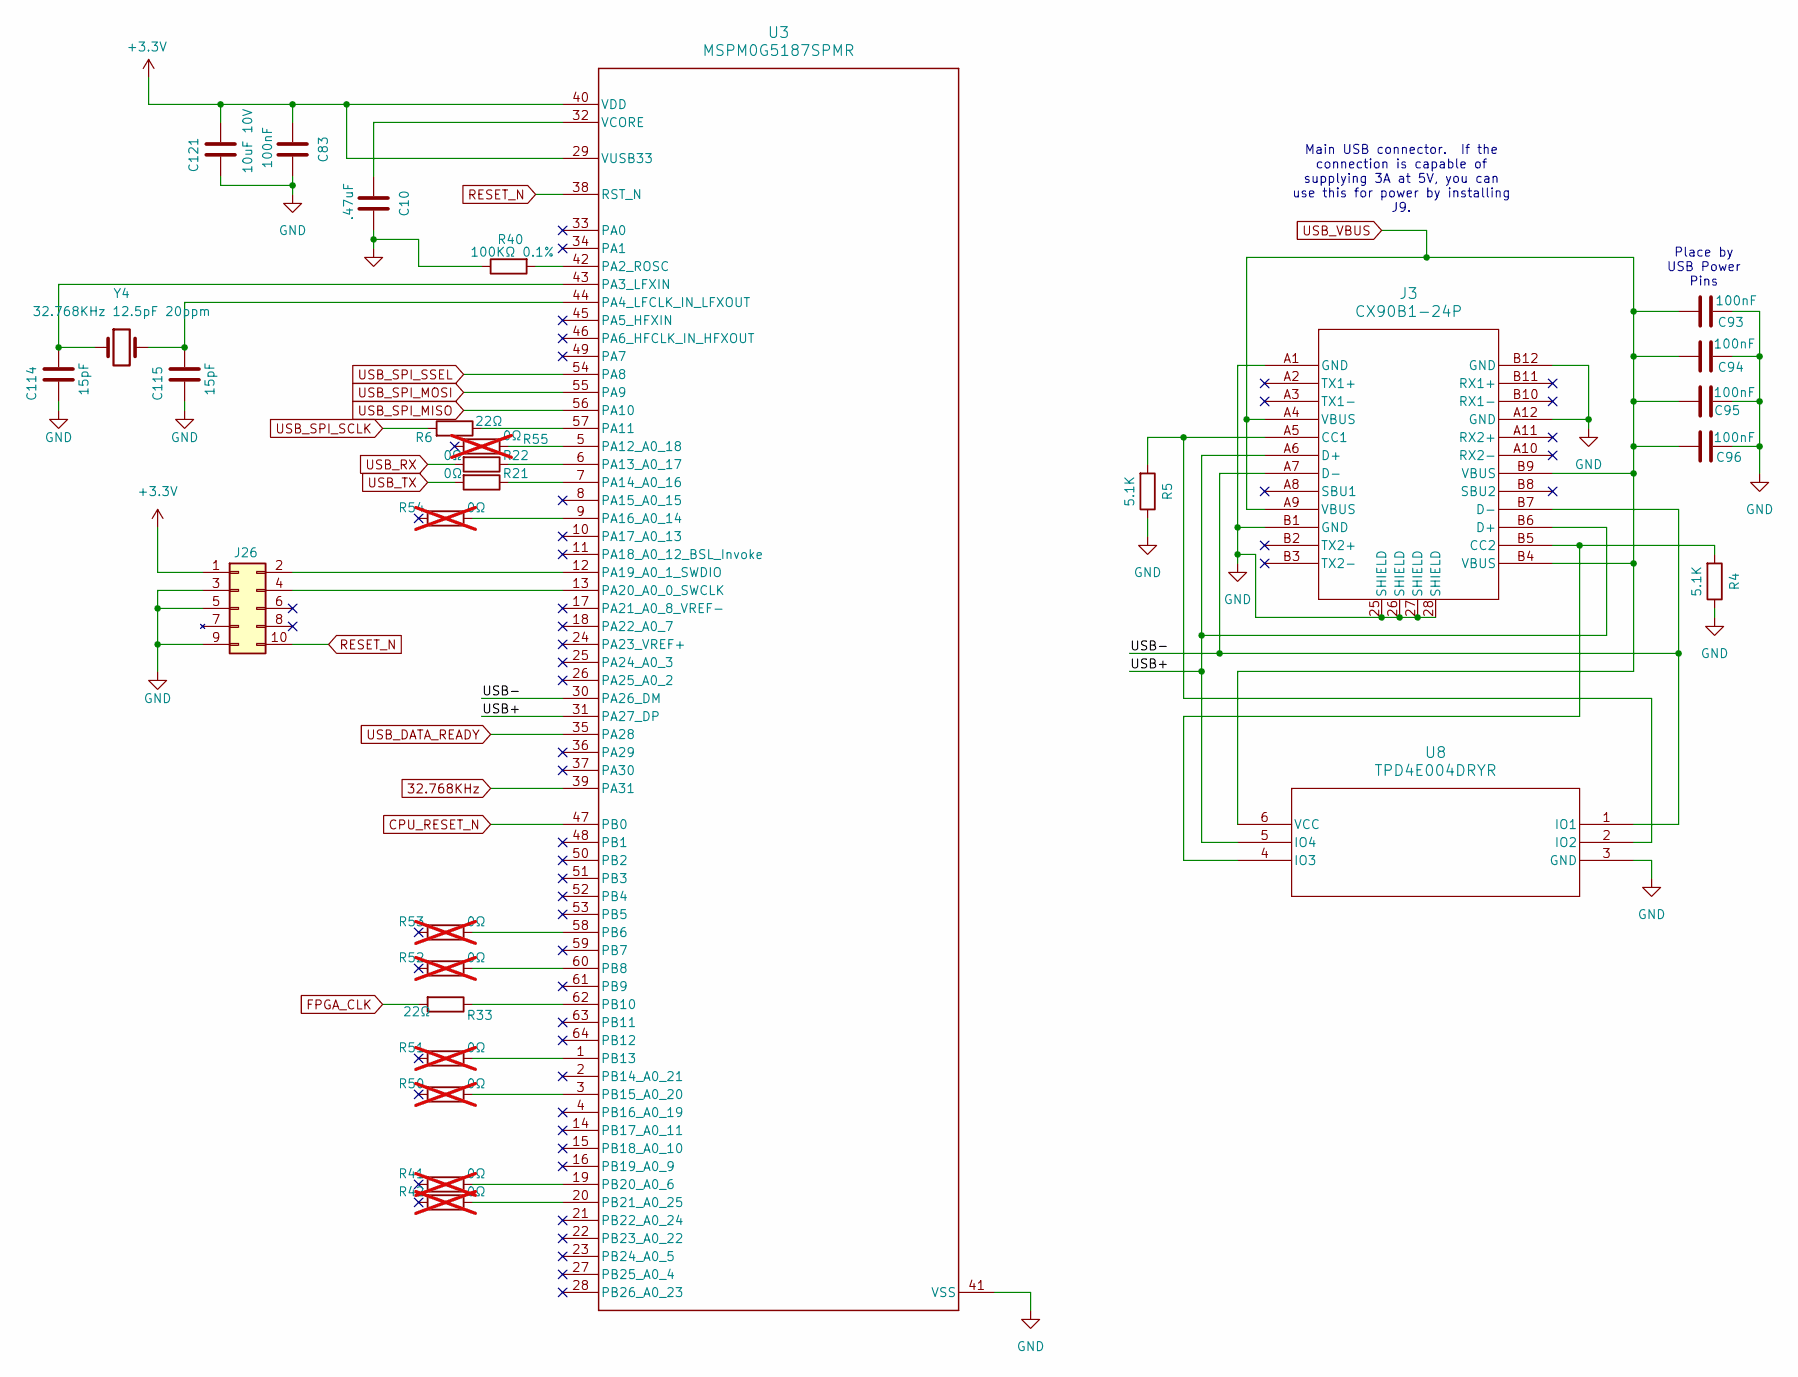
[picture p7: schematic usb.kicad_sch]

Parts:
C10: .47uF; C_0603_1608Metric_Pad1.08x0.95mm_HandSolder
C83, C93, C94, C95, C96: 100nF; C_0402_1005Metric
C114, C115: 15pF; C_0402_1005Metric_Pad0.74x0.62mm_HandSolder
C121: 10uF 10V; C_1206_3216Metric_Pad1.33x1.80mm_HandSolder
J3: CX90B1-24P; CX90B1-24P_HIR
J26: FTSH-105-01-L-DV-K
R4, R5: 5.1K; R_0402_1005Metric
R6: 22Ω; R_0402_1005Metric
R21, R22: 0Ω; R_0402_1005Metric
R33: 22Ω; R_0402_1005Metric_Pad0.72x0.64mm_HandSolder
R40: 100KΩ 0.1%; R_0402_1005Metric
R41, R42, R50, R51, R52, R53, R54, R55: 0Ω; R_0402_1005Metric; not fitted
U3: MSPM0G5187SPMR; PM0064A-IPC_A
U8: TPD4E004DRYR; DRY6
Y4: 32.768KHz 12.5pF 20ppm; Crystal_SMD_2012-2Pin_2.0x1.2mm

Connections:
32.768KHz: U3.39 (PA31); also elsewhere on the board
+3.3V: C83.2, C121.2, J26.1 (VTREF), U3.29 (VUSB33), U3.40 (VDD); also elsewhere on the board
/USB/USB+: J3.A6 (D+), J3.B6 (D+), U3.31 (PA27_DP), U8.5 (IO4)
/USB/USB-: J3.A7 (D-), J3.B7 (D-), U3.30 (PA26_DM), U8.1 (IO1)
CPU_RESET_N: U3.47 (PB0); also elsewhere on the board
FPGA_CLK: R33.2; also elsewhere on the board
GND: C10.1, C83.1, C93.2, C94.2, C95.2, C96.2, C114.1, C115.1, C121.1, J3.25 (SHIELD), J3.26 (SHIELD), J3.27 (SHIELD), J3.28 (SHIELD), J3.A1 (GND), J3.A12 (GND), J3.B1 (GND), J3.B12 (GND), J26.3 (GND), J26.5 (GND), J26.9 (GND), R4.1, R5.1, R40.1, U3.41 (VSS), U8.3 (GND); also elsewhere on the board
unnamed: J3.A5 (CC1), R5.2, U8.2 (IO2)
unnamed: J3.B5 (CC2), R4.2, U8.4 (IO3)
unnamed: J26.4 (TCK), U3.13 (PA20_A0_0_SWCLK)
unnamed: J26.2 (TMS), U3.12 (PA19_A0_1_SWDIO)
unnamed: R40.2, U3.42 (PA2_ROSC)
unnamed: C114.2, U3.43 (PA3_LFXIN), Y4.1
unnamed: C115.2, U3.44 (PA4_LFCLK_IN_LFXOUT), Y4.2
unnamed: R6.1, U3.57 (PA11)
unnamed: R55.1, U3.5 (PA12_A0_18)
unnamed: R22.1, U3.6 (PA13_A0_17)
unnamed: R21.1, U3.7 (PA14_A0_16)
unnamed: R54.1, U3.9 (PA16_A0_14)
unnamed: R53.1, U3.58 (PB6)
unnamed: R52.1, U3.60 (PB8)
unnamed: R33.1, U3.62 (PB10)
unnamed: R51.1, U3.1 (PB13)
unnamed: R50.1, U3.3 (PB15_A0_20)
unnamed: R41.1, U3.19 (PB20_A0_6)
unnamed: R42.1, U3.20 (PB21_A0_25)
unnamed: C10.2, U3.32 (VCORE)
RESET_N: J26.10 (NRST), U3.38 (RST_N); also elsewhere on the board
USB_DATA_READY: U3.35 (PA28); also elsewhere on the board
USB_RX: R22.2; also elsewhere on the board
USB_SPI_MISO: U3.56 (PA10); also elsewhere on the board
USB_SPI_MOSI: U3.55 (PA9); also elsewhere on the board
USB_SPI_SCLK: R6.2; also elsewhere on the board
USB_SPI_SSEL: U3.54 (PA8); also elsewhere on the board
USB_TX: R21.2; also elsewhere on the board
USB_VBUS: C93.1, C94.1, C95.1, C96.1, J3.A4 (VBUS), J3.A9 (VBUS), J3.B4 (VBUS), J3.B9 (VBUS), U8.6 (VCC); also elsewhere on the board

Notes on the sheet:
Place by USB Power Pins
Main USB connector. If the connection is capable of supplying 3A at 5V, you can use this for power by installing J9.

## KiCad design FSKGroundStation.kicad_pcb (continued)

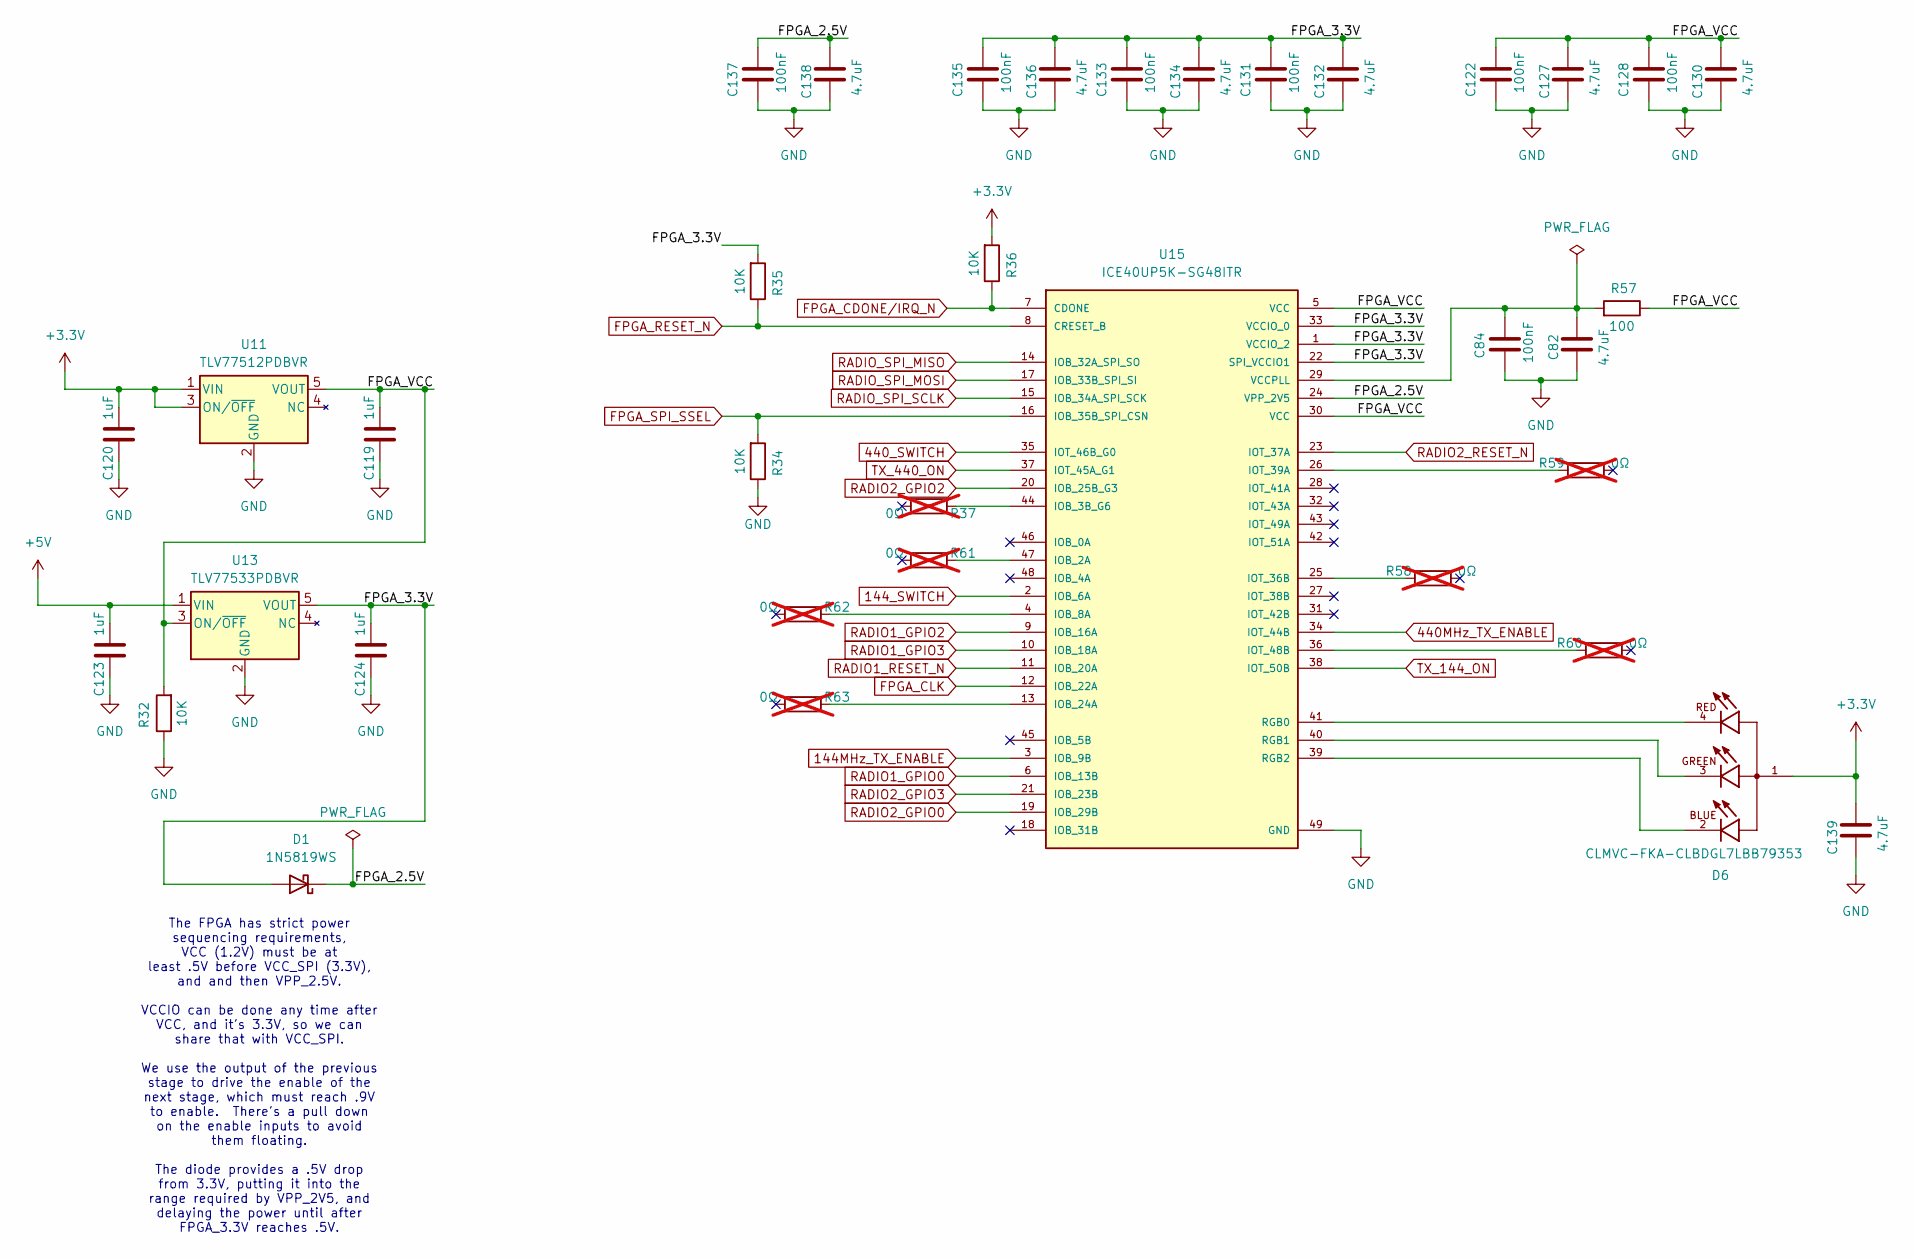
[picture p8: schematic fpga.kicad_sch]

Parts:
C82, C127, C130, C132, C134, C136, C138, C139: 4.7uF; C_0603_1608Metric_Pad1.08x0.95mm_HandSolder
C84, C122, C128, C131, C133, C135, C137: 100nF; C_0402_1005Metric_Pad0.74x0.62mm_HandSolder
C119, C120, C123, C124: 1uF; C_0603_1608Metric_Pad1.08x0.95mm_HandSolder
D1: 1N5819WS; D_SOD-323
D6: CLMVC-FKA-CLBDGL7LBB79353; LED_CLMVC-FKA-CLBDGL7LBB79353; PARTREV 14
R32, R34, R35, R36: 10K; R_0402_1005Metric
R37, R58, R59, R60, R61, R62, R63: 0Ω; R_0402_1005Metric_Pad0.72x0.64mm_HandSolder; not fitted
R57: 100; R_0402_1005Metric
U11: TLV77512PDBVR; SOT-23-5
U13: TLV77533PDBVR; SOT-23-5
U15: ICE40UP5K-SG48ITR; QFN50P700X700X100-49N; DigiKey_Part_Number 220-2155-1-ND

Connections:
144MHz_TX_ENABLE: U15.3 (IOB_9B); also elsewhere on the board
144_SWITCH: U15.2 (IOB_6A); also elsewhere on the board
440MHz_TX_ENABLE: U15.34 (IOT_44B); also elsewhere on the board
440_SWITCH: U15.35 (IOT_46B_G0); also elsewhere on the board
+3.3V: C120.2, C139.2, D6.1, R36.2, U11.1 (VIN), U11.3 (ON/~OFF); also elsewhere on the board
+5V: C123.2, U13.1 (VIN); also elsewhere on the board
/FPGA/FPGA_2.5V: C137.2, C138.2, D1.1 (K), U15.24 (VPP_2V5)
/FPGA/FPGA_3.3V: C124.2, C131.2, C132.2, C133.2, C134.2, C135.2, C136.2, D1.2 (A), R35.2, U13.5 (VOUT), U15.1 (VCCIO_2), U15.22 (SPI_VCCIO1), U15.33 (VCCIO_0)
/FPGA/FPGA_VCC: C119.2, C122.2, C127.2, C128.2, C130.2, R32.2, R57.1, U11.5 (VOUT), U13.3 (ON/~OFF), U15.5 (VCC), U15.30 (VCC)
FPGA_CDONE/IRQ_N: R36.1, U15.7 (CDONE); also elsewhere on the board
FPGA_CLK: U15.12 (IOB_22A); also elsewhere on the board
FPGA_RESET_N: R35.1, U15.8 (CRESET_B); also elsewhere on the board
FPGA_SPI_SSEL: R34.2, U15.16 (IOB_35B_SPI_CSN); also elsewhere on the board
GND: C82.1, C84.1, C119.1, C120.1, C122.1, C123.1, C124.1, C127.1, C128.1, C130.1, C131.1, C132.1, C133.1, C134.1, C135.1, C136.1, C137.1, C138.1, C139.1, R32.1, R34.1, U11.2 (GND), U13.2 (GND), U15.49 (GND); also elsewhere on the board
unnamed: R61.1, U15.47 (IOB_2A)
unnamed: R37.1, U15.44 (IOB_3B_G6)
unnamed: R62.1, U15.4 (IOB_8A)
unnamed: R63.1, U15.13 (IOB_24A)
unnamed: R58.1, U15.25 (IOT_36B)
unnamed: R59.1, U15.26 (IOT_39A)
unnamed: R60.1, U15.36 (IOT_48B)
unnamed: D6.4, U15.41 (RGB0)
unnamed: D6.3, U15.40 (RGB1)
unnamed: D6.2, U15.39 (RGB2)
unnamed: C82.2, C84.2, R57.2, U15.29 (VCCPLL)
RADIO1_GPIO0: U15.6 (IOB_13B); also elsewhere on the board
RADIO1_GPIO2: U15.9 (IOB_16A); also elsewhere on the board
RADIO1_GPIO3: U15.10 (IOB_18A); also elsewhere on the board
RADIO1_RESET_N: U15.11 (IOB_20A); also elsewhere on the board
RADIO2_GPIO0: U15.19 (IOB_29B); also elsewhere on the board
RADIO2_GPIO2: U15.20 (IOB_25B_G3); also elsewhere on the board
RADIO2_GPIO3: U15.21 (IOB_23B); also elsewhere on the board
RADIO2_RESET_N: U15.23 (IOT_37A); also elsewhere on the board
RADIO_SPI_MISO: U15.14 (IOB_32A_SPI_SO); also elsewhere on the board
RADIO_SPI_MOSI: U15.17 (IOB_33B_SPI_SI); also elsewhere on the board
RADIO_SPI_SCLK: U15.15 (IOB_34A_SPI_SCK); also elsewhere on the board
TX_144_ON: U15.38 (IOT_50B); also elsewhere on the board
TX_440_ON: U15.37 (IOT_45A_G1); also elsewhere on the board

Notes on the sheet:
The FPGA has strict power sequencing requirements, VCC (1.2V) must be at least .5V before VCC_SPI (3.3V), and and then VPP_2.5V. VCCIO can be done any time after VCC, and it's 3.3V, so we can share that with VCC_SPI. We use the output of the previous stage to drive the enable of the next stage, whi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

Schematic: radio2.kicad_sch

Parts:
C14: 10nF; C_0402_1005Metric_Pad0.74x0.62mm_HandSolder
C16, C29: 1nF; C_0402_1005Metric_Pad0.74x0.62mm_HandSolder
C17, C18, C19, C20, C21, C22, C23, C24, C25, C26, C27: 47nF; C_0402_1005Metric_Pad0.74x0.62mm_HandSolder
C28: 220nF; C_0402_1005Metric_Pad0.74x0.62mm_HandSolder
C49: 39pF 1%; C_0402_1005Metric_Pad0.74x0.62mm_HandSolder
C53: 56pF 1%; C_0402_1005Metric_Pad0.74x0.62mm_HandSolder
C85: 100nF; C_0402_1005Metric_Pad0.74x0.62mm_HandSolder
L18: 56nH; L_0603_1608Metric_Pad1.05x0.95mm_HandSolder
R7: 56K 1%; R_0402_1005Metric
R14: 0Ω; R_0402_1005Metric
R16: 18Ω; R_0402_1005Metric
R31: 0Ω; R_0402_1005Metric; not fitted
U14: CC1125RHBR; RHB32_3P45X3P45_TEX
Y1: OW2EL89CENUXK7YLC-40M; Oscillator_SMD_SiT_PQFN-4Pin_2.0x1.6mm

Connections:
440_PA: C49.2; also elsewhere on the board
440_RX_N: U14.20 (LNA_N); also elsewhere on the board
440_RX_P: U14.19 (LNA_P); also elsewhere on the board
440_TRX_SW: U14.18 (TRX_SW); also elsewhere on the board
+3.3V: C19.2, C20.2, C21.2, C22.2, C23.2, C24.2, C25.2, C26.2, C27.2, C53.2, C85.2, R16.2, U14.1 (VDD_GUARD), U14.5 (DVDD), U14.12 (DVDD), U14.13 (AVDD_IF), U14.15 (AVDD_RF), U14.22 (AVDD_SYNTH1), U14.25 (AVDD_PFD_CHP), U14.27 (AVDD_SYNTH2), U14.28 (AVDD_XOSC), Y1.4 (V+); also elsewhere on the board
GND: C14.1, C17.1, C18.1, C19.1, C20.1, C21.1, C22.1, C23.1, C24.1, C25.1, C26.1, C27.1, C28.1, C85.1, R7.1, R31.1, U14.30 (XOSC_Q1), U14.33 (EPAD), Y1.2 (GND); also elsewhere on the board
unnamed: C29.2, R14.1, R31.2
unnamed: C53.1, L18.2, R16.1
unnamed: C28.2, U14.6 (DCPL)
unnamed: C18.2, U14.26 (DCPL_PFD_CHP)
unnamed: C14.2, U14.21 (DCPL_VCO)
unnamed: C17.2, U14.29 (DCPL_XOSC)
unnamed: C29.1, U14.32 (EXT_XOSC)
unnamed: C16.1, U14.23 (LPF0)
unnamed: C16.2, U14.24 (LPF1)
unnamed: C49.1, L18.1, U14.17 (PA)
unnamed: R7.2, U14.14 (RBIAS)
unnamed: R14.2, Y1.3 (OUT)
RADIO2_GPIO0: U14.10 (GPIO0); also elsewhere on the board
RADIO2_GPIO2: U14.4 (GPIO2); also elsewhere on the board
RADIO2_GPIO3: U14.3 (GPIO3); also elsewhere on the board
RADIO2_RESET_N: U14.2 (RESET_N); also elsewhere on the board
RADIO2_SPI_SSEL: U14.11 (CSN); also elsewhere on the board
RADIO_SPI_MISO: U14.9 (SO(GPIO1)); also elsewhere on the board
RADIO_SPI_MOSI: U14.7 (SI); also elsewhere on the board
RADIO_SPI_SCLK: U14.8 (SCLK); also elsewhere on the board

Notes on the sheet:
This is in case we need to reduce the voltage into the oscillator pin.
Decoupling, place one by each power pin.

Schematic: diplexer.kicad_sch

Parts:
C112: 5pF ±.1; C_0402_1005Metric_Pad0.74x0.62mm_HandSolder
C129: 14pF 1%; C_0402_1005Metric_Pad0.74x0.62mm_HandSolder
J22: BWSMA-KWE-Z001; CONN_BWSMA-KWE-Z001_BAT
J23: SJ-3524-SMT; CUI_SJ-3524-SMT; PARTREV 1.03
L23, L24, L40: 470nH; L_0805_2012Metric_Pad1.05x1.20mm_HandSolder
L35: 220nH 2%; L_0805_2012Metric_Pad1.05x1.20mm_HandSolder
L44: 27nH 2%; L_0603_1608Metric_Pad1.05x0.95mm_HandSolder
Q1, Q2: BSS138; SOT-23
R25, R26: 10K; R_0402_1005Metric
R27, R28, R97: 10K; R_0402_1005Metric_Pad0.72x0.64mm_HandSolder

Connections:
GND: J22.2, J22.3, J22.4, J22.5, J23.1, Q1.2 (S), Q2.2 (S), R25.1, R26.1, R27.2, R28.2, R97.2; also elsewhere on the board
unnamed: C112.2, L35.1
unnamed: C129.1, L44.2
unnamed: J22.1, L24.1, L35.2, L44.1
unnamed: L23.2, R27.1
unnamed: L24.2, R28.1
unnamed: L40.2, R97.1
unnamed: J23.2, Q1.3 (D)
unnamed: J23.3, Q2.3 (D)
RF_144: C112.1, L23.1; also elsewhere on the board
RF_440: C129.2, L40.1; also elsewhere on the board
TX_144_ON: Q2.1 (G), R26.2; also elsewhere on the board
TX_440_ON: Q1.1 (G), R25.2; also elsewhere on the board

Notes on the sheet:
Inductor to bleed off static build up on the antenna.
Combined 144/440 antenna port. You lose 1dB using this.
Control output for controlling external things like amplifiers. Open when receiving, short to ground when transmitting.

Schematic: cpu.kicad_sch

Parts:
C2, C3, C4, C5, C6, C7, C8, C9, C108, C109, C110: 100nF; C_0402_1005Metric_Pad0.74x0.62mm_HandSolder
C15: 10uF; C_1206_3216Metric_Pad1.33x1.80mm_HandSolder
C111, C113: 0; C_0402_1005Metric_Pad0.74x0.62mm_HandSolder; not fitted
D4: YELLOW LED; LED_0603_1608Metric_Pad1.05x0.95mm_HandSolder
J1: FTSH-105-01-L-DV-K
J24: HTSW-103-07-G-S; CON3_1X3_TU_TSW
L2: 6.8uH; L_1210_3225Metric_Pad1.42x2.65mm_HandSolder
R1, R56: 10K; R_0402_1005Metric
R20: 22Ω; R_0402_1005Metric
R39: 3KΩ; R_0603_1608Metric_Pad0.98x0.95mm_HandSolder
R46: 22Ω; R_0402_1005Metric_Pad0.72x0.64mm_HandSolder; not fitted
R47: 0Ω; R_0402_1005Metric_Pad0.72x0.64mm_HandSolder; not fitted
U4: CC2755P105E0WRHAR; RHA40_4P5X4P5
U12: SN74AHC1G09QDCKRQ1; DCK5
Y2: 48MHZ 7PF 20ppm; Crystal_SMD_2016-4Pin_2.0x1.6mm

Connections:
2.4G_ANT: U4.39 (ANT); also elsewhere on the board
32.768KHz: U4.26 (DIO23_X32P); also elsewhere on the board
144_PA_TEMP: U4.21 (DIO19_A6); also elsewhere on the board
440_PA_TEMP: U4.22 (DIO20_A5); also elsewhere on the board
+3.3V: C2.2, C3.2, C4.2, C7.2, C8.2, C9.2, D4.2 (A), J1.1 (VTREF), R1.2, R56.2, U4.9 (VDDIO), U4.17 (VDDIO), U4.18 (VDDS), U4.29 (VDDS), U4.31 (VDDS), U4.38 (VDDS), U12.5 (VCC); also elsewhere on the board
/CPU/CPU_RESET2_N: C5.2, J1.10 (NRST), R1.1, U4.25 (nRST), U12.4 (Y)
/CPU/VDDR: C15.2, C108.2, C109.2, C110.2, L2.1, U4.1 (VDDR), U4.2 (VDDR), U4.34 (VDDR)
CPU_RESET_N: R56.1, U12.1 (A); also elsewhere on the board
FPGA_CDONE/IRQ_N: U4.20 (DIO18_A7); also elsewhere on the board
FPGA_RESET_N: U4.16 (DIO16); also elsewhere on the board
FPGA_SPI_SSEL: U4.23 (DIO21_A4); also elsewhere on the board
GND: C2.1, C3.1, C4.1, C5.1, C6.1, C7.1, C8.1, C9.1, C15.1, C108.1, C109.1, C110.1, C111.1, C113.1, J1.3 (GND), J1.5 (GND), J1.9 (GND), J24.3, U4.40 (RFGND), U4.41 (EPAD), U12.3 (GND), Y2.2 (G), Y2.4 (G); also elsewhere on the board
unnamed: D4.1 (K), R39.1
unnamed: L2.2, U4.30 (DCDC_SW)
unnamed: R39.2, U4.3 (DIO0)
unnamed: R20.2, U4.15 (DIO15)
unnamed: R46.1, U4.27 (DIO24_X32N)
unnamed: R47.1, U4.33 (DIO28_A0)
unnamed: C6.2, U4.28 (VDDD)
unnamed: C111.2, U4.36 (X48N), Y2.1
unnamed: C113.2, U4.35 (X48P), Y2.3
RADIO1_SPI_SSEL: U4.24 (DIO22_A3); also elsewhere on the board
RADIO2_SPI_SSEL: U4.19 (DIO17_A8); also elsewhere on the board
RADIO_SPI_MISO: U4.14 (DIO12); also elsewhere on the board
RADIO_SPI_MOSI: U4.13 (DIO11); also elsewhere on the board
RADIO_SPI_SCLK: R20.1; also elsewhere on the board
RESET_N: U12.2 (B); also elsewhere on the board
SWDCK: J1.4 (TCK), U4.11 (DIO9_SWDIO)
SWDIO: J1.2 (TMS), U4.12 (DIO10_SWDCK)
USB_DATA_READY: U4.32 (DIO27_A1); also elsewhere on the board
USB_RX: J24.1, U4.4 (DIO1); also elsewhere on the board
USB_SPI_MISO: U4.8 (DIO5); also elsewhere on the board
USB_SPI_MOSI: U4.7 (DIO4); also elsewhere on the board
USB_SPI_SCLK: U4.6 (DIO3); also elsewhere on the board
USB_SPI_SSEL: U4.10 (DIO7); also elsewhere on the board
USB_TX: J24.2, U4.5 (DIO2); also elsewhere on the board

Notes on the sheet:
TODO - VDDR can also be supplied using an internal LDO, look into that so we can get rid of these parts.
The USB interface provides a 32.768KHz clock, we use that here.

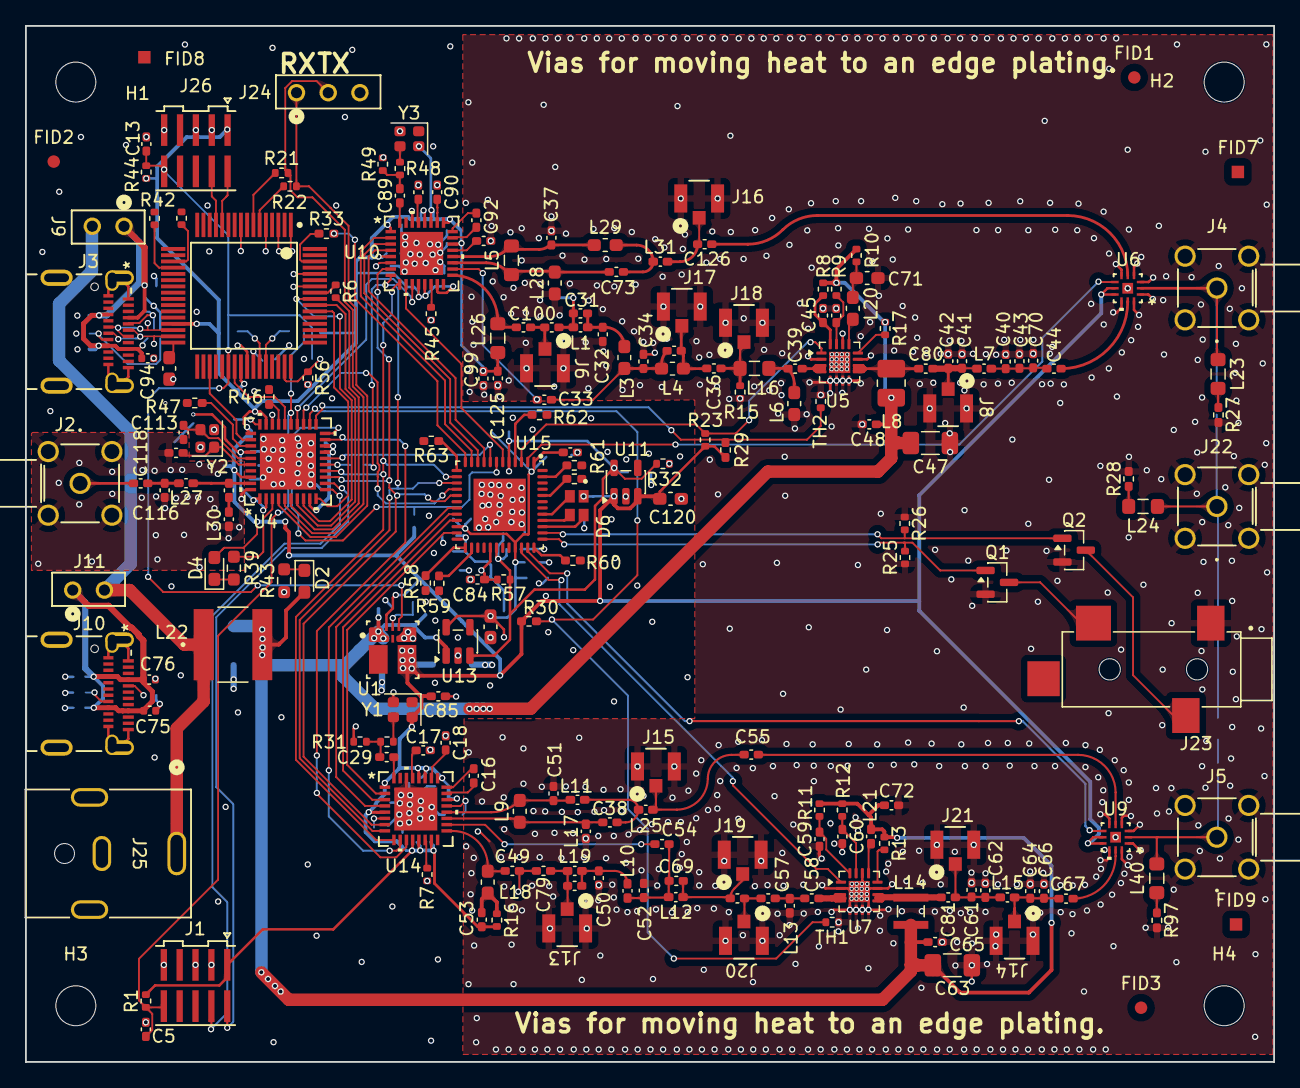
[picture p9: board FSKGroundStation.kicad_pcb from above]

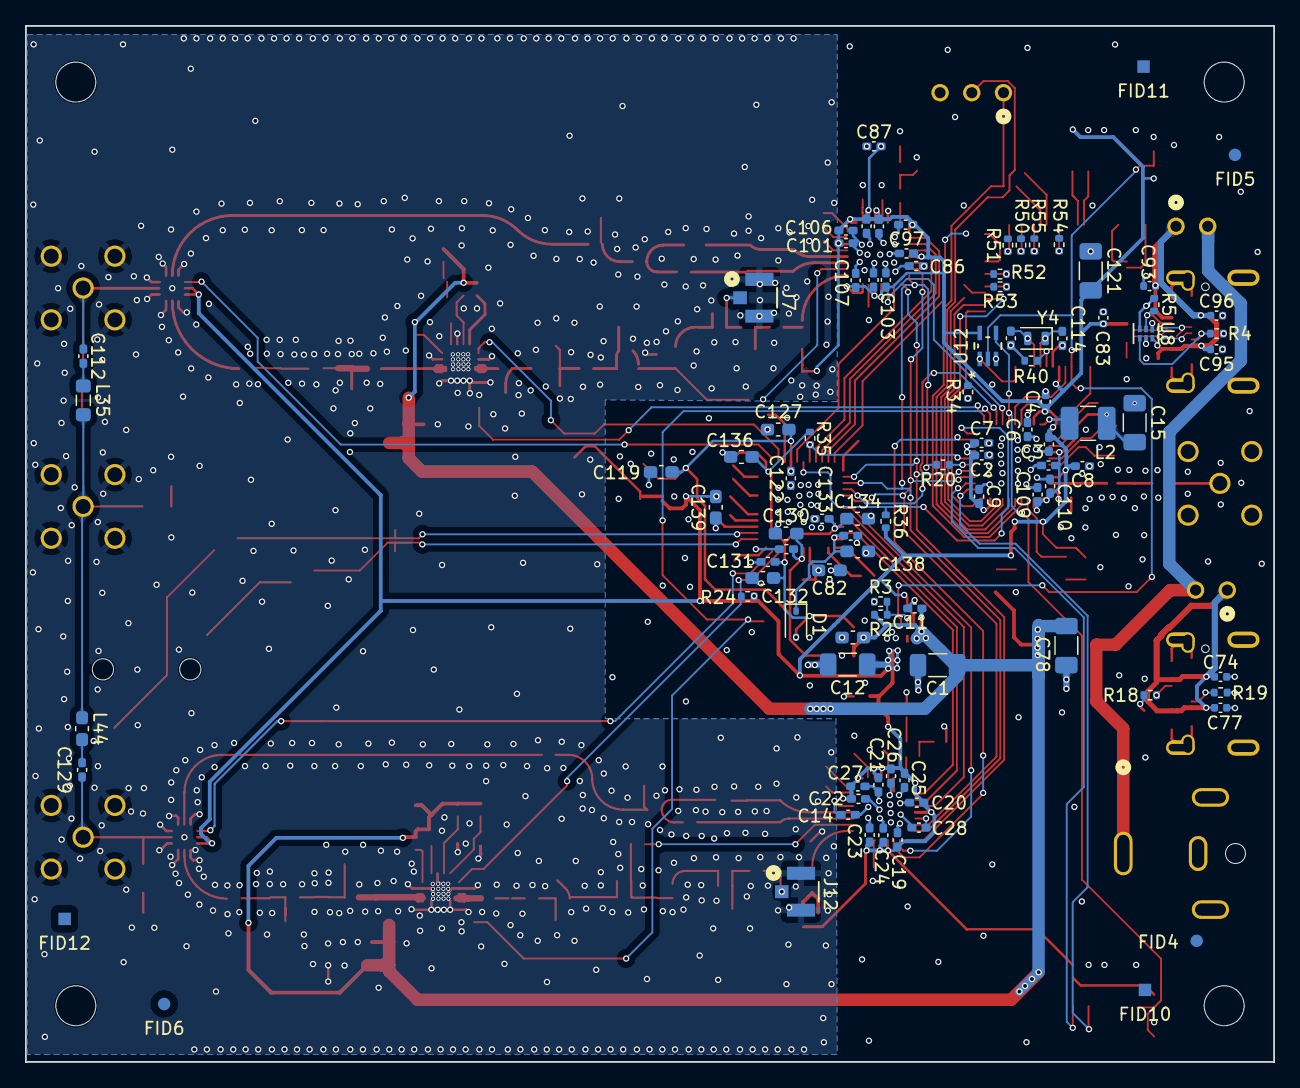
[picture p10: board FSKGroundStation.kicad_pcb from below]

Board: 4 copper layers, 100.0 x 83.0 mm, 304 parts (96 on the bottom side), 176 nets.

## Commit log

2026-03-01 Finish up inputting things
    [144MHz.kicad_sch, 440MHz.kicad_sch, cpu.kicad_sch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]
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2026-03-01 More cleanups and add some test points
    [144MHz.kicad_sch, 440MHz.kicad_sch, cpu.kicad_sch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]
2026-03-01 Add more test points
    [144MHz.kicad_sch, 440MHz.kicad_sch]
2026-03-01 Start on PCB
    Clean up a lot of issues.
    [440MHz.kicad_sch, FSKGroundStation.kicad_pcb, cpu.kicad_sch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]
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2026-03-02 Add some things missed in the previous commit
    [diplexer.kicad_sch]
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2026-03-02 More track cleanup
    Add teardrops, etc.
    [FSKGroundStation.kicad_pcb]
2026-03-02 Reduce hole sizes and add more holes on PA
    Meet spec requirements.
    [144MHz.kicad_sch, 440MHz.kicad_sch, FSKGroundStation.kicad_pcb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]
2026-03-02 Increase power trace widths
    1mm for main +5V.
    [FSKGroundStation.kicad_pcb]
2026-03-02 Start working on BOM, fix supply indoctors
    [144MHz.kicad_sch, 440MHz.kicad_sch, FSKGroundStation.kicad_pcb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]
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2026-03-02 Fix the value of a capacitor
    It was 27pF, not 28pF.
    [440MHz.kicad_sch, FSKGroundStation.kicad_pcb]
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2026-03-03 Add pull up on the PA enables
    So they are off by default.
    [144MHz.kicad_sch, 440MHz.kicad_sch, FSKGroundStation.kicad_pcb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]
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2026-03-03 Add pulldowns on the external control transistor inputs
    So they are disabled by default.
    [FSKGroundStation.kicad_pcb, diplexer.kicad_sch]
2026-03-03 Change a resistor on the 150MHz TX
    No need to have a 2K and a 1.96K resistor for this, just use 1.96K
    on both.
    [144MHz.kicad_sch, FSKGroundStation.kicad_pcb]
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2026-03-03 Add a barrel-type power connector
    Make supplying power a little simpler.
    [FSKGroundStation.kicad_pcb, power.kicad_sch]
2026-03-03 Fix the 440 PA to work at 430-450
    [440MHz.kicad_sch, FSKGroundStation.kicad_pcb]
2026-03-03 Move RF parts from the bottom of the board to the top
    This will allow a heat sink to be more easily mounted.
    [FSKGroundStation.kicad_pcb]
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2026-03-03 Adjust the thermsistors a bit
    Keep the bottom ground plan as clean as possible, make sure there are
    plenty of vias around the termsistor, and avoid messing up the coplanar
    areas around some RF traces.
    [FSKGroundStation.kicad_pcb]
2026-03-03 Forgot to do a save on the previous commit
    [FSKGroundStation.kicad_pcb]
2026-03-03 Increase the board width to 82.5mm
    To be sure it will work in the chassis.
    [FSKGroundStation.kicad_pcb]
2026-03-03 Increase the board width to 83mm
    The slot it's supposed to go into is 84mm wide, it appears 82mm in the
    middle. 83mm should be good.
    According to a post on Amazon, the length is 103mm total with the inside
    dimension 100mm.
    [FSKGroundStation.kicad_pcb]
2026-03-04 Add some more notes on heat sink options
    [FSKGroundStation.kicad_pcb]
2026-03-04 Rework the cc1125 matching networks
    Per combining information from the 169MHz PA design (to separate the PA
    and LNA outputs) and the 440 design (to get the component values).
    [440MHz.kicad_sch, FSKGroundStation.kicad_pcb]
2026-03-04 Control the 440 switch directly from the CPU
    The RX/TX switch on the CC1125 added a lot of complexity with the inverter
    and such. Instead, just drive it frmo the CC1125.
    Use the RX/TX switch on the CC1125 as an option shown on the design with
    169MHz and an external PA, not populated.
    [440MHz.kicad_sch, FSKGroundStation.kicad_pcb, cpu.kicad_sch]
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2026-03-04 More vias
    Make sure the grounds are well connected.
    [FSKGroundStation.kicad_pcb]
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2026-03-04 Adjust the location of a U.FL test connector
    Put it at the input of the 440 LNA match, it moved since an inductor was
    added.
    [440MHz.kicad_sch, FSKGroundStation.kicad_pcb]
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2026-03-04 Directly power the oscillators
    There is only one D/A converter on the CC1312R, so you really couldn't
    power both of the oscillators from that chip. Power is not a concern,
    so just directly power them from 3.3V. That required using a different
    oscillator chip, too, but it was available on both frequencies.
    [FSKGroundStation.kicad_pcb, cpu.kicad_sch, radio2.kicad_sch]
2026-03-04 Fix the BOM for the previous change
2026-03-04 Fix some oscillator issues
    Ground an unused oscillator line on the CC1125 that needs to be grounded
    in external oscillator mode.
    Add a resistor divider to the oscillator inputs in case the voltage
    needs to be decreased. It should be fixable with the internal capacitor
    tuning, but just in case.
    [FSKGroundStation.kicad_pcb, cpu.kicad_sch, radio2.kicad_sch]
2026-03-04 Make a bunch of GPIOs more easily available
    Put them on DNP zero-ohm resistors.
    [FSKGroundStation.kicad_pcb, cpu.kicad_sch, radio2.kicad_sch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]
2026-03-04 Forgot to do a save before the last commit.
    [FSKGroundStation.kicad_pcb]
2026-03-04 Add a bunch of vias for moving heat to an edge plate
    The theory is you can do edge plating on the board and have the heat
    move from the PA, through the various ground layers on the board to
    the vias, then through the edge plate to the chassis.
    [FSKGroundStation.kicad_pcb]
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2026-03-07 First start at reworking to get HDLC
    [2_4g.kicad_sch, FSKGroundStation.kicad_pcb, FSKGroundStation.kicad_sch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]
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2026-03-09 Fix CC2745 layout
    Some pins were wrong.
    Also clean up a lot of layout issues caused by setting the clearance so
    low to get the FPGA to route. Set it back to normal constraints and
    mark all the FPGA exclusions.
    [FSKGroundStation.kicad_pcb, cpu.kicad_sch]
2026-03-09 Change the cc2745 to a cc2755
    Same pinout, cheaper, not automotive.
    [FSKGroundStation.kicad_pcb, cpu.kicad_sch]
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2026-03-10 Fix a wrong component value on 2.5GHz
    [2_4g.kicad_sch, FSKGroundStation.kicad_pcb]
2026-03-10 Fix some layout issues with recent changes
    [FSKGroundStation.kicad_pcb]
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2026-03-10 Fix some components messed up by the previous change
    [144MHz.kicad_sch, 440MHz.kicad_sch, cpu.kicad_sch]
2026-03-11 Rewire the radio SPI pins
    They couldn't go on the pins they were on.
    [cpu.kicad_sch]
2026-03-11 More track cleanups for USB and the CPU
    Make things a little neater.
    [cpu.kicad_sch]
2026-03-11 Use a diode to provide the 2.5V voltage for the FPGA
    Drops 3.3V down to 2.8V, which is in range. It's a lot simpler.
    Also do some via cleanup.
    [fpga.kicad_sch]
2026-03-11 Add a DNP resistor on an FPGA pin
    Make it available for use. Clean up routing around the FPGA a bit, too.
    [FSKGroundStation.kicad_pcb, fpga.kicad_sch]
2026-03-11 Switch to a CPU with a USB interface for the USB connection
    The part that was picked had proprietary tools and configuration and it
    didn't support interrupts. The CPU is cheaper and more capable.
    [FSKGroundStation.kicad_pcb, cpu.kicad_sch, fpga.kicad_sch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]
2026-03-11 Add a blue LED to the power line
    [FSKGroundStation.kicad_pcb]
2026-03-11 Add some missing footprints
2026-03-11 Missed the schematic save on the new LED
    [power.kicad_sch]
2026-03-12 Track cleanup around the USB
    Make things cleaner.
    [FSKGroundStation.kicad_pcb]
2026-03-12 Add a clock from the USB chip to the FPGA
    The FPGA might need a clock for certain things, so provide it.
    [FSKGroundStation.kicad_pcb, cpu.kicad_sch, fpga.kicad_sch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]
2026-03-13 Split the USB CPU and main CPU reset lines
    [FSKGroundStation.kicad_pcb, cpu.kicad_sch, power.kicad_sch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]
2026-03-13 Split the CPU reset line a little better
    Make it so either the main reset line or the reset line from the USB
    device will reset the CPU.
    [FSKGroundStation.kicad_pcb, cpu.kicad_sch]
2026-03-13 Move he FPGA clock to pin 62 on the USB chip
    That is easily drivable with PWM, if I can figure out how that works.
    [FSKGroundStation.kicad_pcb, usb.kicad_sch]
2026-03-14 Fix some BOM issues
2026-03-16 Add DNP resistors on the unused pins of the CPU and the USB chip
    Move a few things to improve the layout, too.
    [FSKGroundStation.kicad_pcb, cpu.kicad_sch, usb.kicad_sch]
2026-03-16 Move the diplexer parts close to the sources
    So there's not a big stub when not using the diplexer.
    [FSKGroundStation.kicad_pcb, cpu.kicad_sch]
2026-03-17 Some notes and via and track fixes
    [FSKGroundStation.kicad_pcb]
2026-03-20 Move the GPIOs for heat removal closer to the edge
    The need to be in contact with the chassis.
    [FSKGroundStation.kicad_pcb]
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2026-04-07 Replace the FPGA with a QFP one
    It has more pins, which might be useful, and it's easier to work with
    than the BGA. It also has a built-in SPI. It's currently an ICE40UP5K,
    but the ICE5LP[124]K chips are pin compatible and cheaper.
    [FSKGroundStation.kicad_pcb, fpga.kicad_sch]
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
